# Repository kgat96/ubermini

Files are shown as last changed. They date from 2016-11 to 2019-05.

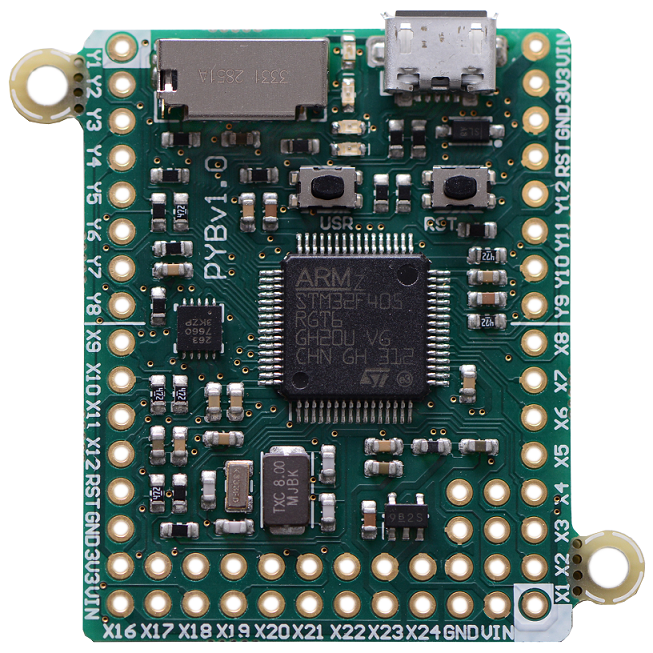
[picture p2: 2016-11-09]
hardware/pyboard/pinout/pybv10b/pybv10b-front-trans.png

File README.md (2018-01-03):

# ubermini

Project Ubermini is an open source wireless development platform suitable for Bluetooth experimentation. Ubermini ships with a capable BLE (Bluetooth Smart) sniffer and can sniff some data from Basic Rate (BR) Bluetooth Classic connections.

clone [Ubertooth](https://github.com/greatscottgadgets/ubertooth) project

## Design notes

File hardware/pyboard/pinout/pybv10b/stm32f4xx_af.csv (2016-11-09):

Port |  | AF0 | AF1 | AF2 | AF3 | AF4 | AF5 | AF6 | AF7 | AF8 | AF9 | AF10 | AF11 | AF12 | AF13 | AF14 | AF15
 |  | SYS | TIM1/2 | TIM3/4/5 | TIM8/9/10/11 | I2C1/2/3 | SPI1/SPI2/I2S2/I2S2ext | SPI3/I2Sext/I2S3 | USART1/2/3/I2S3ext | UART4/5/USART6 | CAN1/CAN2/TIM12/13/14 | OTG_FS/OTG_HS | ETH | FSMC/SDIO/OTG_FS | DCMI |  |  | ADC
PortA | PA0 |  | TIM2_CH1/TIM2_ETR | TIM5_CH1 | TIM8_ETR |  |  |  | USART2_CTS | UART4_TX |  |  | ETH_MII_CRS |  |  |  | EVENTOUT | ADC123_IN0
PortA | PA1 |  | TIM2_CH2 | TIM5_CH2 |  |  |  |  | USART2_RTS | UART4_RX |  |  | ETH_MII_RX_CLK/ETH_RMII__REF_CLK |  |  |  | EVENTOUT | ADC123_IN1
PortA | PA2 |  | TIM2_CH3 | TIM5_CH3 | TIM9_CH1 |  |  |  | USART2_TX |  |  |  | ETH_MDIO |  |  |  | EVENTOUT | ADC123_IN2
PortA | PA3 |  | TIM2_CH4 | TIM5_CH4 | TIM9_CH2 |  |  |  | USART2_RX |  |  | OTG_HS_ULPI_D0 | ETH_MII_COL |  |  |  | EVENTOUT | ADC123_IN3
PortA | PA4 |  |  |  |  |  | SPI1_NSS | SPI3_NSS/I2S3_WS | USART2_CK |  |  |  |  | OTG_HS_SOF | DCMI_HSYNC |  | EVENTOUT | ADC12_IN4
PortA | PA5 |  | TIM2_CH1/TIM2_ETR |  | TIM8_CH1N |  | SPI1_SCK |  |  |  |  | OTG_HS_ULPI_CK |  |  |  |  | EVENTOUT | ADC12_IN5
PortA | PA6 |  | TIM1_BKIN | TIM3_CH1 | TIM8_BKIN |  | SPI1_MISO |  |  |  | TIM13_CH1 |  |  |  | DCMI_PIXCK |  | EVENTOUT | ADC12_IN6
PortA | PA7 |  | TIM1_CH1N | TIM3_CH2 | TIM8_CH1N |  | SPI1_MOSI |  |  |  | TIM14_CH1 |  | ETH_MII_RX_DV/ETH_RMII_CRS_DV |  |  |  | EVENTOUT | ADC12_IN7
PortA | PA8 | MCO1 | TIM1_CH1 |  |  | I2C3_SCL |  |  | USART1_CK |  |  | OTG_FS_SOF |  |  |  |  | EVENTOUT
PortA | PA9 |  | TIM1_CH2 |  |  | I2C3_SMBA |  |  | USART1_TX |  |  |  |  |  | DCMI_D0 |  | EVENTOUT
PortA | PA10 |  | TIM1_CH3 |  |  |  |  |  | USART1_RX |  |  | OTG_FS_ID |  |  | DCMI_D1 |  | EVENTOUT
PortA | PA11 |  | TIM1_CH4 |  |  |  |  |  | USART1_CTS |  | CAN1_RX | OTG_FS_DM |  |  |  |  | EVENTOUT
PortA | PA12 |  | TIM1_ETR |  |  |  |  |  | USART1_RTS |  | CAN1_TX | OTG_FS_DP |  |  |  |  | EVENTOUT
PortA | PA13 | JTMS-SWDIO |  |  |  |  |  |  |  |  |  |  |  |  |  |  | EVENTOUT
PortA | PA14 | JTCK-SWCLK |  |  |  |  |  |  |  |  |  |  |  |  |  |  | EVENTOUT
PortA | PA15 | JTDI | TIM2_CH1/TIM2_ETR |  |  |  | SPI1_NSS | SPI3_NSS/I2S3_WS |  |  |  |  |  |  |  |  | EVENTOUT
PortB | PB0 |  | TIM1_CH2N | TIM3_CH3 | TIM8_CH2N |  |  |  |  |  |  | OTG_HS_ULPI_D1 | ETH_MII_RXD2 |  |  |  | EVENTOUT | ADC12_IN8
PortB | PB1 |  | TIM1_CH3N | TIM3_CH4 | TIM8_CH3N |  |  |  |  |  |  | OTG_HS_ULPI_D2 | ETH_MII_RXD3 |  |  |  | EVENTOUT | ADC12_IN9
PortB | PB2 |  |  |  |  |  |  |  |  |  |  |  |  |  |  |  | EVENTOUT
PortB | PB3 | JTDO/TRACESWO | TIM2_CH2 |  |  |  | SPI1_SCK | SPI3_SCK/I2S3_CK |  |  |  |  |  |  |  |  | EVENTOUT
PortB | PB4 | NJTRST |  | TIM3_CH1 |  |  | SPI1_MISO | SPI3_MISO | I2S3ext_SD |  |  |  |  |  |  |  | EVENTOUT
PortB | PB5 |  |  | TIM3_CH2 |  | I2C1_SMBA | SPI1_MOSI | SPI3_MOSI/I2S3_SD |  |  | CAN2_RX | OTG_HS_ULPI_D7 | ETH_PPS_OUT |  | DCMI_D10 |  | EVENTOUT
PortB | PB6 |  |  | TIM4_CH1 |  | I2C1_SCL |  |  | USART1_TX |  | CAN2_TX |  |  |  | DCMI_D5 |  | EVENTOUT
PortB | PB7 |  |  | TIM4_CH2 |  | I2C1_SDA |  |  | USART1_RX |  |  |  |  | FSMC_NL | DCMI_VSYNC |  | EVENTOUT
PortB | PB8 |  |  | TIM4_CH3 | TIM10_CH1 | I2C1_SCL |  |  |  |  | CAN1_RX |  | ETH_MII_TXD3 | SDIO_D4 | DCMI_D6 |  | EVENTOUT
PortB | PB9 |  |  | TIM4_CH4 | TIM11_CH1 | I2C1_SDA | SPI2_NSS/I2S2_WS |  |  |  | CAN1_TX |  |  | SDIO_D5 | DCMI_D7 |  | EVENTOUT
PortB | PB10 |  | TIM2_CH3 |  |  | I2C2_SCL | SPI2_SCK/I2S2_CK |  | USART3_TX |  |  | OTG_HS_ULPI_D3 | ETH_MII_RX_ER |  |  |  | EVENTOUT
PortB | PB11 |  | TIM2_CH4 |  |  | I2C2_SDA |  |  | USART3_RX |  |  | OTG_HS_ULPI_D4 | ETH_MII_TX_EN/ETH_RMII_TX_EN |  |  |  | EVENTOUT
PortB | PB12 |  | TIM1_BKIN |  |  | I2C2_SMBA | SPI2_NSS/I2S2_WS |  | USART3_CK |  | CAN2_RX | OTG_HS_ULPI_D5 | ETH_MII_TXD0/ETH_RMII_TXD0 | OTG_HS_ID |  |  | EVENTOUT
PortB | PB13 |  | TIM1_CH1N |  |  |  | SPI2_SCK/I2S2_CK |  | USART3_CTS |  | CAN2_TX | OTG_HS_ULPI_D6 | ETH_MII_TXD1/ETH_RMII_TXD1 |  |  |  | EVENTOUT
PortB | PB14 |  | TIM1_CH2N |  | TIM8_CH2N |  | SPI2_MISO | I2S2ext_SD | USART3_RTS |  | TIM12_CH1 |  |  | OTG_HS_DM |  |  | EVENTOUT
PortB | PB15 | RTC_REFIN | TIM1_CH3N |  | TIM8_CH3N |  | SPI2_MOSI/I2S2_SD |  |  |  | TIM12_CH2 |  |  | OTG_HS_DP |  |  | EVENTOUT
PortC | PC0 |  |  |  |  |  |  |  |  |  |  | OTG_HS_ULPI_STP |  |  |  |  | EVENTOUT | ADC123_IN10
PortC | PC1 |  |  |  |  |  |  |  |  |  |  |  | ETH_MDC |  |  |  | EVENTOUT | ADC123_IN11
PortC | PC2 |  |  |  |  |  | SPI2_MISO | I2S2ext_SD |  |  |  | OTG_HS_ULPI_DIR | ETH_MII_TXD2 |  |  |  | EVENTOUT | ADC123_IN12
PortC | PC3 |  |  |  |  |  | SPI2_MOSI/I2S2_SD |  |  |  |  | OTG_HS_ULPI_NXT | ETH_MII_TX_CLK |  |  |  | EVENTOUT | ADC123_IN13
PortC | PC4 |  |  |  |  |  |  |  |  |  |  |  | ETH_MII_RXD0/ETH_RMII_RXD0 |  |  |  | EVENTOUT | ADC123_IN14
PortC | PC5 |  |  |  |  |  |  |  |  |  |  |  | ETH_MII_RXD1/ETH_RMII_RXD1 |  |  |  | EVENTOUT | ADC123_IN15
PortC | PC6 |  |  | TIM3_CH1 | TIM8_CH1 |  | I2S2_MCK |  |  | USART6_TX |  |  |  | SDIO_D6 | DCMI_D0 |  | EVENTOUT
PortC | PC7 |  |  | TIM3_CH2 | TIM8_CH2 |  |  | I2S3_MCK |  | USART6_RX |  |  |  | SDIO_D7 | DCMI_D1 |  | EVENTOUT
PortC | PC8 |  |  | TIM3_CH3 | TIM8_CH3 |  |  |  |  | USART6_CK |  |  |  | SDIO_D0 | DCMI_D2 |  | EVENTOUT
PortC | PC9 | MCO2 |  | TIM3_CH4 | TIM8_CH4 | I2C3_SDA | I2S_CKIN |  |  |  |  |  |  | SDIO_D1 | DCMI_D3 |  | EVENTOUT
PortC | PC10 |  |  |  |  |  |  | SPI3_SCK/I2S3_CK | USART3_TX | UART4_TX |  |  |  | SDIO_D2 | DCMI_D8 |  | EVENTOUT
PortC | PC11 |  |  |  |  |  | I2S3ext_SD | SPI3_MISO | USART3_RX | UART4_RX |  |  |  | SDIO_D3 | DCMI_D4 |  | EVENTOUT
PortC | PC12 |  |  |  |  |  |  | SPI3_MOSI/I2S3_SD | USART3_CK | UART5_TX |  |  |  | SDIO_CK | DCMI_D9 |  | EVENTOUT
PortC | PC13 |  |  |  |  |  |  |  |  |  |  |  |  |  |  |  | EVENTOUT
PortC | PC14 |  |  |  |  |  |  |  |  |  |  |  |  |  |  |  | EVENTOUT
PortC | PC15 |  |  |  |  |  |  |  |  |  |  |  |  |  |  |  | EVENTOUT
PortD | PD0 |  |  |  |  |  |  |  |  |  | CAN1_RX |  |  | FSMC_D2 |  |  | EVENTOUT
PortD | PD1 |  |  |  |  |  |  |  |  |  | CAN1_TX |  |  | FSMC_D3 |  |  | EVENTOUT
PortD | PD2 |  |  | TIM3_ETR |  |  |  |  |  | UART5_RX |  |  |  | SDIO_CMD | DCMI_D11 |  | EVENTOUT
PortD | PD3 |  |  |  |  |  |  |  | USART2_CTS |  |  |  |  | FSMC_CLK |  |  | EVENTOUT
PortD | PD4 |  |  |  |  |  |  |  | USART2_RTS |  |  |  |  | FSMC_NOE |  |  | EVENTOUT
PortD | PD5 |  |  |  |  |  |  |  | USART2_TX |  |  |  |  | FSMC_NWE |  |  | EVENTOUT
PortD | PD6 |  |  |  |  |  |  |  | USART2_RX |  |  |  |  | FSMC_NWAIT |  |  | EVENTOUT
PortD | PD7 |  |  |  |  |  |  |  | USART2_CK |  |  |  |  | FSMC_NE1/FSMC_NCE2 |  |  | EVENTOUT
PortD | PD8 |  |  |  |  |  |  |  | USART3_TX |  |  |  |  | FSMC_D13 |  |  | EVENTOUT
PortD | PD9 |  |  |  |  |  |  |  | USART3_RX |  |  |  |  | FSMC_D14 |  |  | EVENTOUT
PortD | PD10 |  |  |  |  |  |  |  | USART3_CK |  |  |  |  | FSMC_D15 |  |  | EVENTOUT
PortD | PD11 |  |  |  |  |  |  |  | USART3_CTS |  |  |  |  | FSMC_A16 |  |  | EVENTOUT
PortD | PD12 |  |  | TIM4_CH1 |  |  |  |  | USART3_RTS |  |  |  |  | FSMC_A17 |  |  | EVENTOUT
PortD | PD13 |  |  | TIM4_CH2 |  |  |  |  |  |  |  |  |  | FSMC_A18 |  |  | EVENTOUT
PortD | PD14 |  |  | TIM4_CH3 |  |  |  |  |  |  |  |  |  | FSMC_D0 |  |  | EVENTOUT
PortD | PD15 |  |  | TIM4_CH4 |  |  |  |  |  |  |  |  |  | FSMC_D1 |  |  | EVENTOUT
PortE | PE0 |  |  | TIM4_ETR |  |  |  |  |  |  |  |  |  | FSMC_NBL0 | DCMI_D2 |  | EVENTOUT
PortE | PE1 |  |  |  |  |  |  |  |  |  |  |  |  | FSMC_NBL1 | DCMI_D3 |  | EVENTOUT
PortE | PE2 | TRACECLK |  |  |  |  |  |  |  |  |  |  | ETH_MII_TXD3 | FSMC_A23 |  |  | EVENTOUT
PortE | PE3 | TRACED0 |  |  |  |  |  |  |  |  |  |  |  | FSMC_A19 |  |  | EVENTOUT
PortE | PE4 | TRACED1 |  |  |  |  |  |  |  |  |  |  |  | FSMC_A20 | DCMI_D4 |  | EVENTOUT
PortE | PE5 | TRACED2 |  |  | TIM9_CH1 |  |  |  |  |  |  |  |  | FSMC_A21 | DCMI_D6 |  | EVENTOUT
PortE | PE6 | TRACED3 |  |  | TIM9_CH2 |  |  |  |  |  |  |  |  | FSMC_A22 | DCMI_D7 |  | EVENTOUT
PortE | PE7 |  | TIM1_ETR |  |  |  |  |  |  |  |  |  |  | FSMC_D4 |  |  | EVENTOUT
PortE | PE8 |  | TIM1_CH1N |  |  |  |  |  |  |  |  |  |  | FSMC_D5 |  |  | EVENTOUT
PortE | PE9 |  | TIM1_CH1 |  |  |  |  |  |  |  |  |  |  | FSMC_D6 |  |  | EVENTOUT
PortE | PE10 |  | TIM1_CH2N |  |  |  |  |  |  |  |  |  |  | FSMC_D7 |  |  | EVENTOUT
PortE | PE11 |  | TIM1_CH2 |  |  |  |  |  |  |  |  |  |  | FSMC_D8 |  |  | EVENTOUT
PortE | PE12 |  | TIM1_CH3N |  |  |  |  |  |  |  |  |  |  | FSMC_D9 |  |  | EVENTOUT
PortE | PE13 |  | TIM1_CH3 |  |  |  |  |  |  |  |  |  |  | FSMC_D10 |  |  | EVENTOUT
PortE | PE14 |  | TIM1_CH4 |  |  |  |  |  |  |  |  |  |  | FSMC_D11 |  |  | EVENTOUT
PortE | PE15 |  | TIM1_BKIN |  |  |  |  |  |  |  |  |  |  | FSMC_D12 |  |  | EVENTOUT
PortF | PF0 |  |  |  |  | I2C2_SDA |  |  |  |  |  |  |  | FSMC_A0 |  |  | EVENTOUT
PortF | PF1 |  |  |  |  | I2C2_SCL |  |  |  |  |  |  |  | FSMC_A1 |  |  | EVENTOUT
PortF | PF2 |  |  |  |  | I2C2_SMBA |  |  |  |  |  |  |  | FSMC_A2 |  |  | EVENTOUT
PortF | PF3 |  |  |  |  |  |  |  |  |  |  |  |  | FSMC_A3 |  |  | EVENTOUT | ADC3_IN9
PortF | PF4 |  |  |  |  |  |  |  |  |  |  |  |  | FSMC_A4 |  |  | EVENTOUT | ADC3_IN14
PortF | PF5 |  |  |  |  |  |  |  |  |  |  |  |  | FSMC_A5 |  |  | EVENTOUT | ADC3_IN15
PortF | PF6 |  |  |  | TIM10_CH1 |  |  |  |  |  |  |  |  | FSMC_NIORD |  |  | EVENTOUT | ADC3_IN4
PortF | PF7 |  |  |  | TIM11_CH1 |  |  |  |  |  |  |  |  | FSMC_NREG |  |  | EVENTOUT | ADC3_IN5
PortF | PF8 |  |  |  |  |  |  |  |  |  | TIM13_CH1 |  |  | FSMC_NIOWR |  |  | EVENTOUT | ADC3_IN6
PortF | PF9 |  |  |  |  |  |  |  |  |  | TIM14_CH1 |  |  | FSMC_CD |  |  | EVENTOUT | ADC3_IN7
PortF | PF10 |  |  |  |  |  |  |  |  |  |  |  |  | FSMC_INTR |  |  | EVENTOUT | ADC3_IN8
PortF | PF11 |  |  |  |  |  |  |  |  |  |  |  |  |  | DCMI_D12 |  | EVENTOUT
PortF | PF12 |  |  |  |  |  |  |  |  |  |  |  |  | FSMC_A6 |  |  | EVENTOUT
PortF | PF13 |  |  |  |  |  |  |  |  |  |  |  |  | FSMC_A7 |  |  | EVENTOUT
PortF | PF14 |  |  |  |  |  |  |  |  |  |  |  |  | FSMC_A8 |  |  | EVENTOUT
PortF | PF15 |  |  |  |  |  |  |  |  |  |  |  |  | FSMC_A9 |  |  | EVENTOUT
PortG | PG0 |  |  |  |  |  |  |  |  |  |  |  |  | FSMC_A10 |  |  | EVENTOUT
PortG | PG1 |  |  |  |  |  |  |  |  |  |  |  |  | FSMC_A11 |  |  | EVENTOUT
PortG | PG2 |  |  |  |  |  |  |  |  |  |  |  |  | FSMC_A12 |  |  | EVENTOUT
PortG | PG3 |  |  |  |  |  |  |  |  |  |  |  |  | FSMC_A13 |  |  | EVENTOUT
PortG | PG4 |  |  |  |  |  |  |  |  |  |  |  |  | FSMC_A14 |  |  | EVENTOUT
PortG | PG5 |  |  |  |  |  |  |  |  |  |  |  |  | FSMC_A15 |  |  | EVENTOUT
PortG | PG6 |  |  |  |  |  |  |  |  |  |  |  |  | FSMC_INT2 |  |  | EVENTOUT
PortG | PG7 |  |  |  |  |  |  |  |  | USART6_CK |  |  |  | FSMC_INT3 |  |  | EVENTOUT
PortG | PG8 |  |  |  |  |  |  |  |  | USART6_RTS |  |  | ETH_PPS_OUT |  |  |  | EVENTOUT
PortG | PG9 |  |  |  |  |  |  |  |  | USART6_RX |  |  |  | FSMC_NE2/FSMC_NCE3 |  |  | EVENTOUT
PortG | PG10 |  |  |  |  |  |  |  |  |  |  |  |  | FSMC_NCE4_1/FSMC_NE3 |  |  | EVENTOUT
PortG | PG11 |  |  |  |  |  |  |  |  |  |  |  | ETH_MII_TX_EN/ETH_RMII_TX_EN | FSMC_NCE4_2 |  |  | EVENTOUT
PortG | PG12 |  |  |  |  |  |  |  |  | USART6_RTS |  |  |  | FSMC_NE4 |  |  | EVENTOUT
PortG | PG13 |  |  |  |  |  |  |  |  | USART6_CTS |  |  | ETH_MII_TXD0/ETH_RMII_TXD0 | FSMC_A24 |  |  | EVENTOUT
PortG | PG14 |  |  |  |  |  |  |  |  | USART6_TX |  |  | ETH_MII_TXD1/ETH_RMII_TXD1 | FSMC_A25 |  |  | EVENTOUT
PortG | PG15 |  |  |  |  |  |  |  |  | USART6_CTS |  |  |  |  | DCMI_D13 |  | EVENTOUT
PortH | PH0 |  |  |  |  |  |  |  |  |  |  |  |  |  |  |  | EVENTOUT
PortH | PH1 |  |  |  |  |  |  |  |  |  |  |  |  |  |  |  | EVENTOUT
PortH | PH2 |  |  |  |  |  |  |  |  |  |  |  | ETH_MII_CRS |  |  |  | EVENTOUT
PortH | PH3 |  |  |  |  |  |  |  |  |  |  |  | ETH_MII_COL |  |  |  | EVENTOUT
PortH | PH4 |  |  |  |  | I2C2_SCL |  |  |  |  |  | OTG_HS_ULPI_NXT |  |  |  |  | EVENTOUT
PortH | PH5 |  |  |  |  | I2C2_SDA |  |  |  |  |  |  |  |  |  |  | EVENTOUT
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

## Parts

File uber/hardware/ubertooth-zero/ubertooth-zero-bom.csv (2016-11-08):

Reference Designator | Manufacturer | Manufacturer Part Number | Description | Supplier | Supplier Part Number | Price Each | Quantity | Extended Price | Notes
C61,81 | Murata | GRM1555C1HR50CZ01D | CAP CER .5PF 50V C0G 0402 | Mouser | 81-GRM36C0R5C50 | 0.03 | 2 | 0.06
C62 | Murata | GRM1555C1H5R6DZ01D | CAP CER 5.6PF 50V C0G 0402 | Mouser | 81-GRM1555C1H5R6DZ1D | 0.03 | 1 | 0.03
C421,431 | Murata | GRM1555C1H270JZ01D | CAP CER 27PF 50V 5% C0G 0402 | Mouser | 81-GRM1555C1H270JZ01 | 0.03 | 2 | 0.06
C1,4,5 | Murata | GRM1555C1H680JZ01D | CAP CER 68PF 50V 5% C0G 0402 | Mouser | 81-GRM1555C1H680JZ1D | 0.03 | 3 | 0.09
C3 | Murata | GRM155R71E103KA01D | CAP CER 10000PF 25V 10% X7R 0402 | Mouser | 81-GRM36X103K25 | 0.03 | 1 | 0.03
C2,6,7,16,71 | Murata | GRM155R61A104KA01D | CAP CER .1UF 10V 10% X5R 0402 | Mouser | 81-GRM155R61A104KA01 | 0.02 | 4 | 0.08
L62 | Murata | LQG15HS5N6S02D | INDUCTOR 5.6NH 300MA 0402 | Mouser | 81-LQG15HS5N6S02D | 0.04 | 1 | 0.04
L61,81 | Murata | LQW15AN7N5J00D | INDUCTOR 7.5NH 570MA 0402 | Mouser | 81-LQW15AN7N5J00D | 0.31 | 2 | 0.62
L71 | Murata | LQW15AN27NJ00D | INDUCTOR 27NH 280MA 0402 | Mouser | 81-LQW15AN27NJ00D | 0.31 | 1 | 0.31
R451 | KOA Speer | RK73H1ETTP4302F | Thick Film Resistor 1/16W 43K 1% 0402 | Mouser | 660-RK73H1ETTP4302F | 0.06 | 1 | 0.06
U1 | Texas Instruments | CC2400-RTB1 | IC RF TXRX 2.4GHZ LP 48-QFN | Mouser | 595-CC2400-RTB1 | 9.14 | 1 | 9.14
J3 | Connector City | CONREVSMA003.031 | Reverse Polarized SMA Connector | Mouser | 712-CONREVSMA003.031 | 3.08 | 1 | 3.08 | Lower cost alternative: SparkFun WRL-00592 $1.95, SMA also an option
U2 | NXP | LPC1758FBD80,551 | ARM Cortex M3 Micro Controller | Mouser | 771-LPC1758FBD80551 | 8.67 | 1 | 8.67 | may substitute LPC175x
X1 | Abracon | ABMM2-16.000MHZ-E2-T | Crystal +/-20PPM 16MHz | Mouser | 815-ABMM2-16-E2T | 1.16 | 1 | 1.16
X2 | Molex | 48037-1000 | USB & Firewire Connector TYPE A RA SHLDED PLG SMT AU | Mouser | 538-48037-1000 | 2.22 | 1 | 2.22 | better price at Digi-Key
U5 | NXP | IP4220CZ6,125 | ESD Suppressor USB2.0 ESD PROTECT DUAL | Mouser | 771-IP4220CZ6-T/R | 0.18 | 1 | 0.18
U4 | Microchip | MCP1801T-1802I/OT | Low Dropout (LDO) Regulators Hi PSRR 150 mA LDO Vin 10V max Vout 1.8V | Mouser | 579-MCP1801T-1802IOT | 0.52 | 1 | 0.52
U3 | Vishay/Siliconix | SI9183DT-33-T1-E3 | Low Dropout (LDO) Regulator 150mA 3.3V | Mouser | 781-SI9183DT-33-E3 | 0.28 | 1 | 0.28
C14,15,17,18,20,22 | TDK | C1608X7R1E104K | CAP CER 0603 0.1uF 25volts X7R 10% | Mouser | 810-C1608X7R1E104K | 0.03 | 6 | 0.18
R5,6,7,8,9,11 | Xicon | 301-330-RC | Thick Film Resistor 1/16W 330OHMS 5% 0603 | Mouser | 301-330-RC | 0.03 | 6 | 0.18
R1,10,13 | Xicon | 301-10K-RC | Thick Film Resistor 1/16W 10KOHMS 5% 0603 | Mouser | 301-10K-RC | 0.03 | 2 | 0.06
C9 | TDK | C1608C0G1H101J | CAP CER 0603 100pF 50volts C0G 5% | Mouser | 810-C1608C0G1H101J | 0.03 | 1 | 0.03
C8 | TDK | C1608C0G1H221J | CAP CER 0603 220pF 50volts C0G 5% | Mouser | 810-C1608C0G1H221J | 0.03 | 1 | 0.03
R4 | Xicon | 301-1.5K-RC | Thick Film Resistor 1/16W 1.5KOHMS 5% | Mouser | 301-1.5K-RC | 0.03 | 1 | 0.03
R2,3 | Vishay/Dale | CRCW060333R0FKEA | Thick Film Resistor 1/10W 33ohms 1% 0603 | Mouser | 71-CRCW0603-33-E3 | 0.06 | 2 | 0.12
C19,21,23,24 | Murata | GRM188R60J105KA01J | CAP CER 0603 1uF 6.3volts X5R 10% | Mouser | 81-GRM18R60J105KA01J | 0.04 | 4 | 0.16
LEDs |  |  | 0603 LED, various colors |  |  | 0.10 | 6 | 0.60

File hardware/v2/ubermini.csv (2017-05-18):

Id | 代号 | 封装 | 数量 | 名称 | 供应商和REF
1 |  | Symbol_OSHW-Logo_SilkScreen_BIG | 1 | Symbol_OSHW-Logo_SilkScreen_BIG
2 | P3,P2,P7 | U.FL | 3 | sma
3 | U1 | cc2591 | 1 | CC2591
4 | U2 | LQFP-64_10x10mm_Pitch0.5mm | 1 | STM32F405RGTx
5 | C1,C15,C21 | C_0603_HandSoldering | 3 | 100nF
6 | R7,R6 | R_0603_HandSoldering | 2 | 22
7 | D1 | R_0805_HandSoldering | 1 | D
8 | R5,R3,R8,R11,R12,R13,R14,R15 | R_0603_HandSoldering | 8 | 10k
9 | BT1 | Pin_Header_Straight_1x02 | 1 | Battery_Cell
10 | C2 | C_0603_HandSoldering | 1 | 2.2Uf
11 | C3 | C_0603_HandSoldering | 1 | 10uf
12 | C4 | C_0402 | 1 | 2p2
13 | C5 | C_0603_HandSoldering | 1 | 2.2uf
14 | C6,C10,C12,C13 | C_0603_HandSoldering | 4 | 1nF
15 | C7 | C_0603_HandSoldering | 1 | 18nF
16 | C8 | C_0402 | 1 | 1pF
17 | C9 | C_0402 | 1 | 6p8
18 | C11 | C_0603_HandSoldering | 1 | 10pF
19 | C14 | C_0603_HandSoldering | 1 | 68p
20 | C16,C32 | C_0603_HandSoldering | 2 | 10nF
21 | C17,C20 | C_0603_HandSoldering | 2 | 68pF
22 | C18,C19 | C_0603_HandSoldering | 2 | 27pF
23 | C22,C25,C27,C28,C29,C30 | C_0603_HandSoldering | 6 | 4.7uF
24 | C23 | C_0603_HandSoldering | 1 | 1uF
25 | C24,C26,C31 | C_0603_HandSoldering | 3 | 2.2uF
26 | C33 | C_0603_HandSoldering | 1 | 15pF
27 | D2,D3,D4,D5,D6 | LED_0805 | 5 | LED
28 | L1 | C_0402 | 1 | 3nH
29 | L2 | C_0402 | 1 | 2n2
30 | L4 | C_0603_HandSoldering | 1 | FB
31 | P1 | sma | 1 | SMA
32 | P4 | Pin_Header_Straight_1x03 | 1 | uart1
33 | P5 | Pin_Header_Straight_1x03 | 1 | SWD
34 | P6 | Pin_Header_Straight_2x03 | 1 | boot
35 | R1 | R_0603_HandSoldering | 1 | 100k
36 | R2 | R_0603_HandSoldering | 1 | 4k3
37 | R4 | R_0603_HandSoldering | 1 | 43k
38 | R9 | R_0603_HandSoldering | 1 | 49.9k
39 | R10 | R_0603_HandSoldering | 1 | 30.1k
40 | SW1 | SW_SPST_FSMSM | 1 | SW_PUSH
41 | U4 | tps712 | 1 | TPS712XX
42 | U5 | winband_spi_flash | 1 | M25PX32-VMW
43 | J1 | USB_Mini-B_s | 1 | USB_OTG
44 | U3 | cc2400 | 1 | CC2400
45 | Y1 | 3225 | 1 | 16m
46 |  | kg_logo | 1 | LOGO

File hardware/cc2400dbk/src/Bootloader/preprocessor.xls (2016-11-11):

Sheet: defines.h
Replace all code segment definitions in the linker file with the following line:
-Z(CODE)INTVEC,FAR_F,SWITCH,CODE=1F800-1FFFF
Create a file (defines.h) containing the following:
/* definitions generated by preprocessor, copy into defines.h */
#ifndef | PPINC
#define | _ATMEGA128 | // device select: _ATMEGAxxxx
#define | _B1024 | // boot size select: _Bxxx (words)
#include | "iom128.h"
/* definitions for UART control */
#define | BAUD_RATE_LOW_REG | UBRR0L
#define | UART_CONTROL_REG | UCSR0B
#define | ENABLE_TRANSMITTER_BIT | TXEN0
#define | ENABLE_RECEIVER_BIT | RXEN0
#define | UART_STATUS_REG | UCSR0A
#define | TRANSMIT_COMPLETE_BIT | TXC0
#define | RECEIVE_COMPLETE_BIT | RXC0
#define | UART_DATA_REG | UDR0
/* definitions for SPM control */
#define | LOAD_SPM_CONTROL_REGISTER_MACRO | STS SPMCSR, R18
#define | GET_SPM_CONTROL_REGISTER_MACRO | LDS R18, SPMCSR
#define | REENABLE_RWW_BIT | RWWSRE
#define | LARGE_MEMORY
#define | PAGESIZE | 256
#define | APP_END | 129024
/* definitions for AVRProg communication */
#define | PARTCODE | 0x44
#define | SIGNATURE_BYTE_1 | 0x1E
#define | SIGNATURE_BYTE_2 | 0x97
#define | SIGNATURE_BYTE_3 | 0x02
/* define pin for enter-self-prog-mode */
#define | PROGPORT | PORTD
#define | PROGPIN | PIND
#define | PROGCTRL | (1<<PD4)
#define | PROGMODE | !(PROGPIN & PROGCTRL)
/* indicate preprocessor result included */
#define | PPINC
#endif

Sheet: Part definitions
Device | Include file name | Page size (words) | NRWW section size (pages) | Total memory (pages) | Part code (AVRProg) | Signature byte 1 | Signature byte 2 | Signature byte 3 | Baud rate register low | UART Control register | UART Status register | Transmitter enable bit | Receiver enable bit | Transmit complete bit | Receive complete bit | UART Data register | SPM Control register | Use extended IO addressing on SPM Control register | Re-enable RWW section bit | Comments
ATmega8 | iom8.h | 32 | 32 | 128 | 0x77 | 0x1E | 0x93 | 0x07 | UBRRL | UCSRB | UCSRA | TXEN | RXEN | TXC | RXC | UDR | SPMCR | FALSE | RWWSRE
ATmega8515 | iom8515.h | 32 | 32 | 128 |  | 0x1E | 0x93 | 0x06 | UBRRL | UCSRB | UCSRA | TXEN | RXEN | TXC | RXC | UDR | SPMCR | FALSE | RWWSRE
ATmega8535 | iom8535.h | 32 | 32 | 128 |  | 0x1E | 0x93 | 0x08 | UBRRL | UCSRB | UCSRA | TXEN | RXEN | TXC | RXC | UDR | SPMCR | FALSE | RWWSRE
ATmega16 | iom16.h | 64 | 16 | 128 | 0x75 | 0x1E | 0x94 | 0x03 | UBRRL | UCSRB | UCSRA | TXEN | RXEN | TXC | RXC | UDR | SPMCR | FALSE | RWWSRE
ATmega162 | iom162.h | 64 | 16 | 128 |  | 0x1E | 0x94 | 0x04 | UBRR0L | UCSR0B | UCSR0A | TXEN0 | RXEN0 | TXC0 | RXC0 | UDR0 | SPMCR | FALSE | RWWSRE
ATmega163 | iom163.h | 64 | 16 | 128 | 0x66 | 0x1E | 0x94 | 0x02 | UBRRLO | UCSRB | UCSRA | TXEN | RXEN | TXC | RXC | UDR | SPMCR | FALSE | ASRE | All memory is NRWW
ATmega169 | iom169.h | 64 | 16 | 128 |  | 0x1E | 0x94 | 0x05 | UBRR0L | UCSR0B | UCSR0A | TXEN0 | RXEN0 | TXC0 | RXC0 | UDR0 | SPMCSR | FALSE | RWWSRE
ATmega32 | iom32.h | 64 | 32 | 256 |  | 0x1E | 0x95 | 0x02 | UBRRL | UCSRB | UCSRA | TXEN | RXEN | TXC | RXC | UDR | SPMCR | FALSE | RWWSRE
ATmega323 | iom323.h | 64 | 16 | 256 | 0x73 | 0x1E | 0x95 | 0x01 | UBRRL | UCSRB | UCSRA | TXEN | RXEN | TXC | RXC | UDR | SPMCR | FALSE | ASRE | All memory is NRWW
ATmega64 | iom64.h | 128 | 32 | 256 |  | 0x1E | 0x96 | 0x02 | UBRRL | UCSRB | UCSRA | TXEN | RXEN | TXC | RXC | UDR | SPMCR | TRUE | RWWSRE
ATmega128 | iom128.h | 128 | 32 | 512 | 0x44 | 0x1E | 0x97 | 0x02 | UBRR0L | UCSR0B | UCSR0A | TXEN0 | RXEN0 | TXC0 | RXC0 | UDR0 | SPMCSR | TRUE | RWWSRE

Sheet: Processing
Part selected | ATMEGA128 | Selected part
Boot size selected (words) | 1024 | Boot loader section size
Boot size selected (bytes) | 2048
Boot size selected (pages) | 8
IO definition file | "iom128.h" | Name of IO definition file
Part code | 0x44 | Used by AVRprog
Signature byte 1 | 0x1E | Device specific signature bytes
Signature byte 2 | 0x97
Signature byte 3 | 0x02
Page size (words) | 128
Page size (bytes) | 256
NRWW section size (pages) | 32
NRWW section size (bytes) | 8192
Boot too large ? | FALSE | Selected boot loader size too large ?
Boot too small ? | FALSE | Selected boot loader size too small ?
Boot OK ? | TRUE | Selected boot loader size inside allowed range ?
Total Flash size (pages) | 512
Total Flash size (bytes) | 131072
Application size (pages) | 504
Application size (bytes) | 129024
Baud rate low register | UBRR0L | Register names for UART
UART Control register | UCSR0B
UART Status register | UCSR0A
Transmitter enable bit | TXEN0
Receiver enable bit | RXEN0
Transmit complete bit | TXC0
Receive complete bit | RXC0
UART Data register | UDR0
SPM Control register | SPMCSR | Definition for using the SPM instruction
Use extended IO addressing | TRUE
Register used | R18
Load SPM control register | STS SPMCSR, R18
Get SPM control register | LDS R18, SPMCSR
Re-enable RWW section bit | RWWSRE

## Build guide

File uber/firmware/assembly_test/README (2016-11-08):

Follow this procedure to test, rework, and program a new Ubertooth One.  For
reference, see ubertooth-one-hardware/ubertooth-one-assembly.pdf and
ubertooth-one-hardware/ubertooth-one-schematic.pdf in the release package or
use KiCad to view the design files located in hardware/ubertooth-one.

Required Equipment

  - Equipment Under Test (EUT): Ubertooth One with 2 dBi antenna

  - Personal Computer (PC) with two open USB ports

  - Pogoprog, a serial programmer for Ubertooth One

  - USB Mini-B cable to connect Pogoprog to PC

  - USB A extension cable or USB hub to allow access to underside of Ubertooth
	One while it is plugged into the PC

  - A Bluetooth device such as a mobile phone

  - Multi-meter (voltmeter and continuity tester)

Required Software

  - lpc21isp

Visual Inspection

  1. Check EUT for missing components.

  2. Check that components are installed with the correct orientation and
  placement.

  3. Check in particular that R1 and C12 are not soldered together (one side,
  GND, may be together, but the side closest to U1 should not be).

Electrical Inspection

  1. Verify no conductivity across C18.

  2. Verify no conductivity across C22.

  3. Verify no conductivity across C32.
 
  If shorts are detected, carefully inspect (in order) the three capacitors
  listed above, the voltage regulator (U7), bypass capacitors, and all IC pins.

Power On EUT

  1. Connect to EUT the 2 dBi antenna.  Check that the antenna fully screws
  onto the RP-SMA connector.

  2. Plug EUT in to PC with USB A extension cable or USB hub.

  3. The "RST" LED (D5) should be illuminated.  No other LED should be fully
  illuminated, though they may be dimly lit.  D5 indicates that U4 has been
  powered on and passed reset.  If D5 does not illuminate, check D5, R8, R9,
  and pins 11 and 14 on U4.

Program EUT with assembly_test Firmware

  1. Ensure EUT is plugged into PC.

  2. Plug Pogoprog into PC with USB Mini-B cable.

  3. Hold Pogoprog against the "PROGRAM" pads on the underside of EUT as shown
  in the photograph:

    http://ubertooth.sourceforge.net/hardware/program/

  4. on the PC, execute:

    $ make program

  If you have not yet compiled the assembly_test firmware, you will need to
  have a gcc/arm environment set up.  See:

    http://ubertooth.sourceforge.net/firmware/develop/

  5. The 'make program' command will indicate "Download Finished . . . Now
  launching the brand new code" if successful.  If it was not successful, check
  the orientation and contact between the Pogoprog and sample Ubertooth One,
  make sure both are plugged in, and try again.

Automated Test

  1. Unplug EUT from PC and plug back in.

  2. "RST" LED (D5) should illuminate immediately and remain on throughout this
  test.

  3. "TX" LED (D2), "RX" LED (D3), and "USR" LED (D4) should flash twice
  together.  Flashing indicates that the test program is executing on U4.  If
  any of the three LEDs do not flash, check that LED, the adjacent resistor,
  and pins 73, 74, and 75 of U4.

  4. Next, "1V8" LED (D1) should illuminate and remain on.  This indicates that
  U3 is powered on.  If D1 does not illuminate, check D1, R3, R4, U7, and pin
  72 of U4.

  5. Next, "TX" LED (D2) should flash twice and then illuminate and remain on.
  This indicates that U4 is able to communicate with U3.  If D2 does not flash
  and illuminate, check pins 25-35 on U3 and pins 53, 54, 58, 59, 60, and 70 on
  U4.  Check that there is a 1.8 Volt potential across C18.  Check that there
  is a 3.3 Volt potential across C25.

  6. Next, "RX" LED (D3) should flash four times quickly and then illuminate
  and remain on.  This indicates that the 16 MHz crystal oscillator is active
  and supplying clock to both U3 and U4.  If D3 does not flash and illuminate,
  check X1, C19, C21, C29, C31, pins 21, 42, and 43 on U3, and pins 19 and 20
  on U4.

  7. At this point, four LEDs (D1, D2, D3, and D5) should all be on.

  8. Use a mobile phone or other Bluetooth device approximately 1 meter away
  from EUT to initiate an inquiry.  This function is typically called “search
  for new Bluetooth devices” or similar.

  9. During the inquiry, "USR" LED (D4) may flash and should then illuminate
  and remain on.  If D4 flashes but does not remain on after the inquiry, this
  indicates that RF performance is poor.  If D4 does not flash at all, this
  indicates a total RF failure.  Check that a 2 dBi antenna is securely
  connected to P1.  Check L1, L2, C1, C3, and C5.  Check all pins on U1 and U3.
  Check R1, R2, and R17.  Check all bypass capacitors around U1 and U3.  Check
  pins 50, 51, 61, 62, 63, 64, 65, 68, and 69 on U4.

  10. After D4 illuminates, the "USB" LED (D6) may flash and should then
  illuminate and remain on.  This indicates that the PC has established USB
  communication with EUT.  With some non-Linux operating systems, D6 may not
  illuminate.  Depending on the OS running on the PC, you might see a "found
  new hardware" or "install device driver software" dialog instead of
  illumination of D6.  You should be able to use operating system logging or
  reporting (e.g. dmesg on Linux) to see that a USB device with the product
  name "ubertooth assembly_test" has been detected.  This indicates success.
  Cancel any dialog and visually inspect D6 and R15.

  11. If all six LEDs are on (with the possible exception of D6 as mentioned
  above), the Automated Test is successful.  To repeat the Automated Test,
  unplug EUT from PC and plug in again.

Test Complete

  If your Ubertooth One has passed the assembly test procedure, the recommended
  next steps are:

  1. Install the USB bootloader on your Ubertooth One.  See:

	firmware/bootloader/README

  2. Use the bootloader to install the bluetooth_rxtx application firmware.
  See:

    host/usb_dfu/README

  3. Follow the Getting Started guide:

    http://ubertooth.sourceforge.net/usage/start/

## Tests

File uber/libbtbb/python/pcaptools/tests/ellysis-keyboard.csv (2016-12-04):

Depth | Time | Name | Data
0 | 7.248613000 | HID Input 1 | 01 00 00 00 00 00 00 00 00
0 | 7.249863000 | HID Input 1 | 01 00 00 28 00 00 00 00 00
0 | 7.251113000 | HID Input 1 | 01 00 00 00 00 00 00 00 00
0 | 10.646359000 | HID Input 1 | 01 00 00 28 00 00 00 00 00
0 | 10.658858750 | HID Input 1 | 01 00 00 00 00 00 00 00 00
0 | 10.681358750 | HID Input 1 | 01 00 00 28 00 00 00 00 00
0 | 10.758865000 | HID Input 1 | 01 00 00 00 00 00 00 00 00
0 | 10.893876750 | HID Input 1 | 01 00 00 28 00 00 00 00 00
0 | 10.983884250 | HID Input 1 | 01 00 00 00 00 00 00 00 00
0 | 12.558997750 | HID Input 1 | 01 02 00 00 00 00 00 00 00
0 | 13.009032500 | HID Input 1 | 01 02 00 08 00 00 00 00 00
0 | 13.144044625 | HID Input 1 | 01 00 00 08 00 00 00 00 00
0 | 13.189048625 | HID Input 1 | 01 00 00 00 00 00 00 00 00
0 | 13.324059500 | HID Input 1 | 01 00 00 11 00 00 00 00 00
0 | 13.414067500 | HID Input 1 | 01 00 00 11 17 00 00 00 00
0 | 13.459070500 | HID Input 1 | 01 00 00 17 00 00 00 00 00
0 | 13.504074375 | HID Input 1 | 01 00 00 00 00 00 00 00 00
0 | 13.549077875 | HID Input 1 | 01 00 00 08 00 00 00 00 00
0 | 13.594078750 | HID Input 1 | 01 00 00 08 15 00 00 00 00
0 | 13.684083375 | HID Input 1 | 01 00 00 15 00 00 00 00 00
0 | 13.729087500 | HID Input 1 | 01 00 00 00 00 00 00 00 00
0 | 13.774091625 | HID Input 1 | 01 00 00 2C 00 00 00 00 00
0 | 13.864099125 | HID Input 1 | 01 00 00 2C 17 00 00 00 00
0 | 13.865349125 | HID Input 1 | 01 00 00 17 00 00 00 00 00
0 | 13.954107375 | HID Input 1 | 01 00 00 00 00 00 00 00 00
0 | 13.955357375 | HID Input 1 | 01 00 00 0B 00 00 00 00 00
0 | 13.999108000 | HID Input 1 | 01 00 00 0B 08 00 00 00 00
0 | 14.044112125 | HID Input 1 | 01 00 00 08 00 00 00 00 00
0 | 14.089117000 | HID Input 1 | 01 00 00 00 00 00 00 00 00
0 | 14.134119250 | HID Input 1 | 01 00 00 2C 00 00 00 00 00
0 | 14.269131375 | HID Input 1 | 01 00 00 00 00 00 00 00 00
0 | 14.270381375 | HID Input 1 | 01 02 00 00 00 00 00 00 00
0 | 14.404141250 | HID Input 1 | 01 02 00 17 00 00 00 00 00
0 | 14.449145125 | HID Input 1 | 01 02 00 00 00 00 00 00 00
0 | 14.584155625 | HID Input 1 | 01 02 00 06 00 00 00 00 00
0 | 14.674164250 | HID Input 1 | 01 02 00 00 00 00 00 00 00
0 | 14.675414250 | HID Input 1 | 01 02 00 13 00 00 00 00 00
0 | 14.809176000 | HID Input 1 | 01 02 00 00 00 00 00 00 00
0 | 14.854179250 | HID Input 1 | 01 00 00 00 00 00 00 00 00
0 | 14.855429250 | HID Input 1 | 01 00 00 2C 00 00 00 00 00
0 | 14.944184000 | HID Input 1 | 01 00 00 2C 16 00 00 00 00
0 | 14.989186250 | HID Input 1 | 01 00 00 16 00 00 00 00 00
0 | 15.034189500 | HID Input 1 | 01 00 00 16 08 00 00 00 00
0 | 15.079194375 | HID Input 1 | 01 00 00 08 00 00 00 00 00
0 | 15.169201125 | HID Input 1 | 01 00 00 00 00 00 00 00 00
0 | 15.214205250 | HID Input 1 | 01 00 00 14 00 00 00 00 00
0 | 15.349217625 | HID Input 1 | 01 00 00 00 00 00 00 00 00
0 | 15.350467625 | HID Input 1 | 01 00 00 18 00 00 00 00 00
0 | 15.394222125 | HID Input 1 | 01 00 00 18 08 00 00 00 00
0 | 15.439224500 | HID Input 1 | 01 00 00 08 00 00 00 00 00
0 | 15.484228000 | HID Input 1 | 01 00 00 00 00 00 00 00 00
0 | 15.619238750 | HID Input 1 | 01 00 00 11 06 00 00 00 00
0 | 15.620488750 | HID Input 1 | 01 00 00 06 00 00 00 00 00
0 | 15.709246125 | HID Input 1 | 01 00 00 06 08 00 00 00 00
0 | 15.710496125 | HID Input 1 | 01 00 00 08 00 00 00 00 00
0 | 15.754250625 | HID Input 1 | 01 00 00 08 2C 00 00 00 00
0 | 15.799253375 | HID Input 1 | 01 00 00 2C 00 00 00 00 00
0 | 15.844256875 | HID Input 1 | 01 00 00 2C 11 00 00 00 00
0 | 15.889262250 | HID Input 1 | 01 00 00 11 00 00 00 00 00
0 | 15.934265375 | HID Input 1 | 01 00 00 11 18 00 00 00 00
0 | 15.979269125 | HID Input 1 | 01 00 00 18 00 00 00 00 00
0 | 16.024272875 | HID Input 1 | 01 00 00 00 00 00 00 00 00
0 | 16.114280375 | HID Input 1 | 01 00 00 10 00 00 00 00 00
0 | 16.249286750 | HID Input 1 | 01 00 00 10 05 00 00 00 00
0 | 16.294289875 | HID Input 1 | 01 00 00 05 00 00 00 00 00
0 | 16.295540000 | HID Input 1 | 01 00 00 00 00 00 00 00 00
0 | 16.384296125 | HID Input 1 | 01 00 00 08 00 00 00 00 00
0 | 16.474304000 | HID Input 1 | 01 00 00 08 15 00 00 00 00
0 | 16.519306375 | HID Input 1 | 01 00 00 15 00 00 00 00 00
0 | 16.564310750 | HID Input 1 | 01 00 00 00 00 00 00 00 00
0 | 16.834333625 | HID Input 1 | 01 20 00 00 00 00 00 00 00
0 | 16.924341375 | HID Input 1 | 01 20 00 33 00 00 00 00 00
0 | 17.014348625 | HID Input 1 | 01 00 00 33 00 00 00 00 00
0 | 17.059353250 | HID Input 1 | 01 00 00 00 00 00 00 00 00
0 | 17.194365625 | HID Input 1 | 01 00 00 2C 00 00 00 00 00
0 | 17.329375625 | HID Input 1 | 01 00 00 00 00 00 00 00 00
0 | 17.330625625 | HID Input 1 | 01 00 00 17 00 00 00 00 00
0 | 17.419381000 | HID Input 1 | 01 00 00 00 00 00 00 00 00
0 | 17.420631000 | HID Input 1 | 01 00 00 0B 00 00 00 00 00
0 | 17.509384500 | HID Input 1 | 01 00 00 0B 08 00 00 00 00
0 | 17.510634375 | HID Input 1 | 01 00 00 08 00 00 00 00 00
0 | 17.554388500 | HID Input 1 | 01 00 00 08 2C 00 00 00 00
0 | 17.599393125 | HID Input 1 | 01 00 00 2C 00 00 00 00 00
0 | 17.689399750 | HID Input 1 | 01 00 00 00 00 00 00 00 00
0 | 17.734403750 | HID Input 1 | 01 00 00 13 00 00 00 00 00
0 | 17.869416125 | HID Input 1 | 01 00 00 00 00 00 00 00 00
0 | 17.870666125 | HID Input 1 | 01 00 00 15 00 00 00 00 00
0 | 17.959421875 | HID Input 1 | 01 00 00 00 00 00 00 00 00
0 | 18.004424875 | HID Input 1 | 01 00 00 12 00 00 00 00 00
0 | 18.184440500 | HID Input 1 | 01 00 00 00 00 00 00 00 00
0 | 18.185690625 | HID Input 1 | 01 00 00 17 00 00 00 00 00
0 | 18.274448625 | HID Input 1 | 01 00 00 00 00 00 00 00 00
0 | 18.319453375 | HID Input 1 | 01 00 00 12 00 00 00 00 00
0 | 18.409461000 | HID Input 1 | 01 00 00 00 00 00 00 00 00
0 | 18.454464375 | HID Input 1 | 01 00 00 06 00 00 00 00 00
0 | 18.544471500 | HID Input 1 | 01 00 00 06 12 00 00 00 00
0 | 18.545721500 | HID Input 1 | 01 00 00 12 00 00 00 00 00
0 | 18.634478875 | HID Input 1 | 01 00 00 00 00 00 00 00 00
0 | 18.724483000 | HID Input 1 | 01 00 00 0F 00 00 00 00 00
0 | 18.814490375 | HID Input 1 | 01 00 00 0F 2C 00 00 00 00
0 | 18.859493750 | HID Input 1 | 01 00 00 2C 00 00 00 00 00
0 | 18.949501375 | HID Input 1 | 01 00 00 00 00 00 00 00 00
0 | 18.994505500 | HID Input 1 | 01 00 00 18 00 00 00 00 00
0 | 19.129516125 | HID Input 1 | 01 00 00 18 16 00 00 00 00
0 | 19.130766250 | HID Input 1 | 01 00 00 16 00 00 00 00 00
0 | 19.219524125 | HID Input 1 | 01 00 00 16 08 00 00 00 00
0 | 19.220773875 | HID Input 1 | 01 00 00 08 00 00 00 00 00
0 | 19.309531000 | HID Input 1 | 01 00 00 00 00 00 00 00 00
0 | 19.354534125 | HID Input 1 | 01 00 00 16 00 00 00 00 00
0 | 19.444542000 | HID Input 1 | 01 00 00 16 2C 00 00 00 00
0 | 19.445792000 | HID Input 1 | 01 00 00 2C 00 00 00 00 00
0 | 19.579553625 | HID Input 1 | 01 00 00 2C 16 00 00 00 00
0 | 19.580803625 | HID Input 1 | 01 00 00 16 00 00 00 00 00
0 | 19.669561125 | HID Input 1 | 01 00 00 16 08 00 00 00 00
0 | 19.714563625 | HID Input 1 | 01 00 00 08 00 00 00 00 00
0 | 19.759568375 | HID Input 1 | 01 00 00 00 00 00 00 00 00
0 | 19.850826125 | HID Input 1 | 01 00 00 14 00 00 00 00 00
0 | 19.939581000 | HID Input 1 | 01 00 00 00 00 00 00 00 00
0 | 19.940831125 | HID Input 1 | 01 00 00 18 00 00 00 00 00
0 | 20.029584250 | HID Input 1 | 01 00 00 18 08 00 00 00 00
0 | 20.074588375 | HID Input 1 | 01 00 00 08 00 00 00 00 00
0 | 20.075838500 | HID Input 1 | 01 00 00 00 00 00 00 00 00
0 | 20.164594500 | HID Input 1 | 01 00 00 11 00 00 00 00 00
0 | 20.209599125 | HID Input 1 | 01 00 00 11 06 00 00 00 00
0 | 20.254602250 | HID Input 1 | 01 00 00 06 00 00 00 00 00
0 | 20.299605750 | HID Input 1 | 01 00 00 08 00 00 00 00 00
0 | 20.344609375 | HID Input 1 | 01 00 00 08 2C 00 00 00 00
0 | 20.390862750 | HID Input 1 | 01 00 00 2C 00 00 00 00 00
0 | 20.479621250 | HID Input 1 | 01 00 00 2C 11 00 00 00 00
0 | 20.480871250 | HID Input 1 | 01 00 00 11 00 00 00 00 00
0 | 20.524623750 | HID Input 1 | 01 00 00 11 18 00 00 00 00
0 | 20.569627750 | HID Input 1 | 01 00 00 18 00 00 00 00 00
0 | 20.614630625 | HID Input 1 | 01 00 00 00 00 00 00 00 00
0 | 20.659633750 | HID Input 1 | 01 00 00 10 00 00 00 00 00
0 | 20.794646250 | HID Input 1 | 01 00 00 10 05 00 00 00 00
0 | 20.839650500 | HID Input 1 | 01 00 00 05 00 00 00 00 00
0 | 20.840900375 | HID Input 1 | 01 00 00 00 00 00 00 00 00
0 | 20.929658125 | HID Input 1 | 01 00 00 08 00 00 00 00 00
0 | 20.974661000 | HID Input 1 | 01 00 00 08 15 00 00 00 00
0 | 21.019666125 | HID Input 1 | 01 00 00 15 00 00 00 00 00
0 | 21.109672625 | HID Input 1 | 01 00 00 00 00 00 00 00 00
0 | 21.110922625 | HID Input 1 | 01 00 00 16 00 00 00 00 00
0 | 21.199678625 | HID Input 1 | 01 00 00 16 2C 00 00 00 00
0 | 21.244683250 | HID Input 1 | 01 00 00 2C 00 00 00 00 00
0 | 21.289683500 | HID Input 1 | 01 00 00 00 00 00 00 00 00
0 | 21.334685625 | HID Input 1 | 01 00 00 17 00 00 00 00 00
0 | 21.379689625 | HID Input 1 | 01 00 00 17 12 00 00 00 00
0 | 21.424694000 | HID Input 1 | 01 00 00 12 00 00 00 00 00
0 | 21.425944125 | HID Input 1 | 01 00 00 12 2C 00 00 00 00
0 | 21.514699625 | HID Input 1 | 01 00 00 2C 00 00 00 00 00
0 | 21.515949625 | HID Input 1 | 01 00 00 2C 04 00 00 00 00
0 | 21.604709125 | HID Input 1 | 01 00 00 04 00 00 00 00 00
0 | 21.605959125 | HID Input 1 | 01 00 00 00 00 00 00 00 00
0 | 21.694713500 | HID Input 1 | 01 00 00 06 00 00 00 00 00
0 | 21.784722750 | HID Input 1 | 01 00 00 06 0E 00 00 00 00
0 | 21.785972625 | HID Input 1 | 01 00 00 0E 00 00 00 00 00
0 | 21.829726625 | HID Input 1 | 01 00 00 00 00 00 00 00 00
0 | 22.009742500 | HID Input 1 | 01 00 00 11 00 00 00 00 00
0 | 22.010992625 | HID Input 1 | 01 00 00 11 12 00 00 00 00
0 | 22.054743875 | HID Input 1 | 01 00 00 12 00 00 00 00 00
0 | 22.144752500 | HID Input 1 | 01 00 00 12 1A 00 00 00 00
0 | 22.146002500 | HID Input 1 | 01 00 00 1A 00 00 00 00 00
0 | 22.189756125 | HID Input 1 | 01 00 00 1A 08 00 00 00 00
0 | 22.191006125 | HID Input 1 | 01 00 00 00 00 00 00 00 00
0 | 22.234757000 | HID Input 1 | 01 00 00 0F 00 00 00 00 00
0 | 22.414772750 | HID Input 1 | 01 00 00 00 00 00 00 00 00
0 | 22.416022875 | HID Input 1 | 01 00 00 07 00 00 00 00 00
0 | 22.549782750 | HID Input 1 | 01 00 00 00 00 00 00 00 00
0 | 23.269841500 | HID Input 1 | 01 00 00 0A 00 00 00 00 00
0 | 23.359849625 | HID Input 1 | 01 00 00 0A 08 00 00 00 00
0 | 23.404853625 | HID Input 1 | 01 00 00 08 00 00 00 00 00
0 | 23.494860375 | HID Input 1 | 01 00 00 00 00 00 00 00 00
0 | 23.629872625 | HID Input 1 | 01 00 00 2C 00 00 00 00 00
0 | 23.764884000 | HID Input 1 | 01 00 00 00 00 00 00 00 00
0 | 23.809888500 | HID Input 1 | 01 00 00 17 00 00 00 00 00
0 | 23.899893375 | HID Input 1 | 01 00 00 17 0B 00 00 00 00
0 | 23.901143375 | HID Input 1 | 01 00 00 0B 00 00 00 00 00
0 | 23.944895500 | HID Input 1 | 01 00 00 0B 08 00 00 00 00
0 | 23.989898500 | HID Input 1 | 01 00 00 08 00 00 00 00 00
0 | 24.034901500 | HID Input 1 | 01 00 00 08 2C 00 00 00 00
0 | 24.036151500 | HID Input 1 | 01 00 00 2C 00 00 00 00 00
0 | 24.079906625 | HID Input 1 | 01 00 00 2C 15 00 00 00 00
0 | 24.169913375 | HID Input 1 | 01 00 00 2C 15 08 00 00 00
0 | 24.171163250 | HID Input 1 | 01 00 00 2C 08 00 00 00 00
0 | 24.214916375 | HID Input 1 | 01 00 00 08 00 00 00 00 00
0 | 24.216166375 | HID Input 1 | 01 00 00 00 00 00 00 00 00
0 | 24.259920750 | HID Input 1 | 01 00 00 06 00 00 00 00 00
0 | 24.394933000 | HID Input 1 | 01 00 00 00 00 00 00 00 00
0 | 24.439935000 | HID Input 1 | 01 00 00 0C 00 00 00 00 00
0 | 24.574946625 | HID Input 1 | 01 00 00 00 00 00 00 00 00
0 | 24.619951625 | HID Input 1 | 01 00 00 13 00 00 00 00 00
0 | 24.754963125 | HID Input 1 | 01 00 00 13 17 00 00 00 00
0 | 24.756213125 | HID Input 1 | 01 00 00 17 00 00 00 00 00
0 | 24.844968875 | HID Input 1 | 01 00 00 00 00 00 00 00 00
0 | 24.979979750 | HID Input 1 | 01 00 00 2C 00 00 00 00 00
0 | 25.024984125 | HID Input 1 | 01 00 00 00 00 00 00 00 00
0 | 25.610031625 | HID Input 1 | 01 00 00 12 00 00 00 00 00
0 | 25.700039125 | HID Input 1 | 01 00 00 12 09 00 00 00 00
0 | 25.745042375 | HID Input 1 | 01 00 00 09 00 00 00 00 00
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

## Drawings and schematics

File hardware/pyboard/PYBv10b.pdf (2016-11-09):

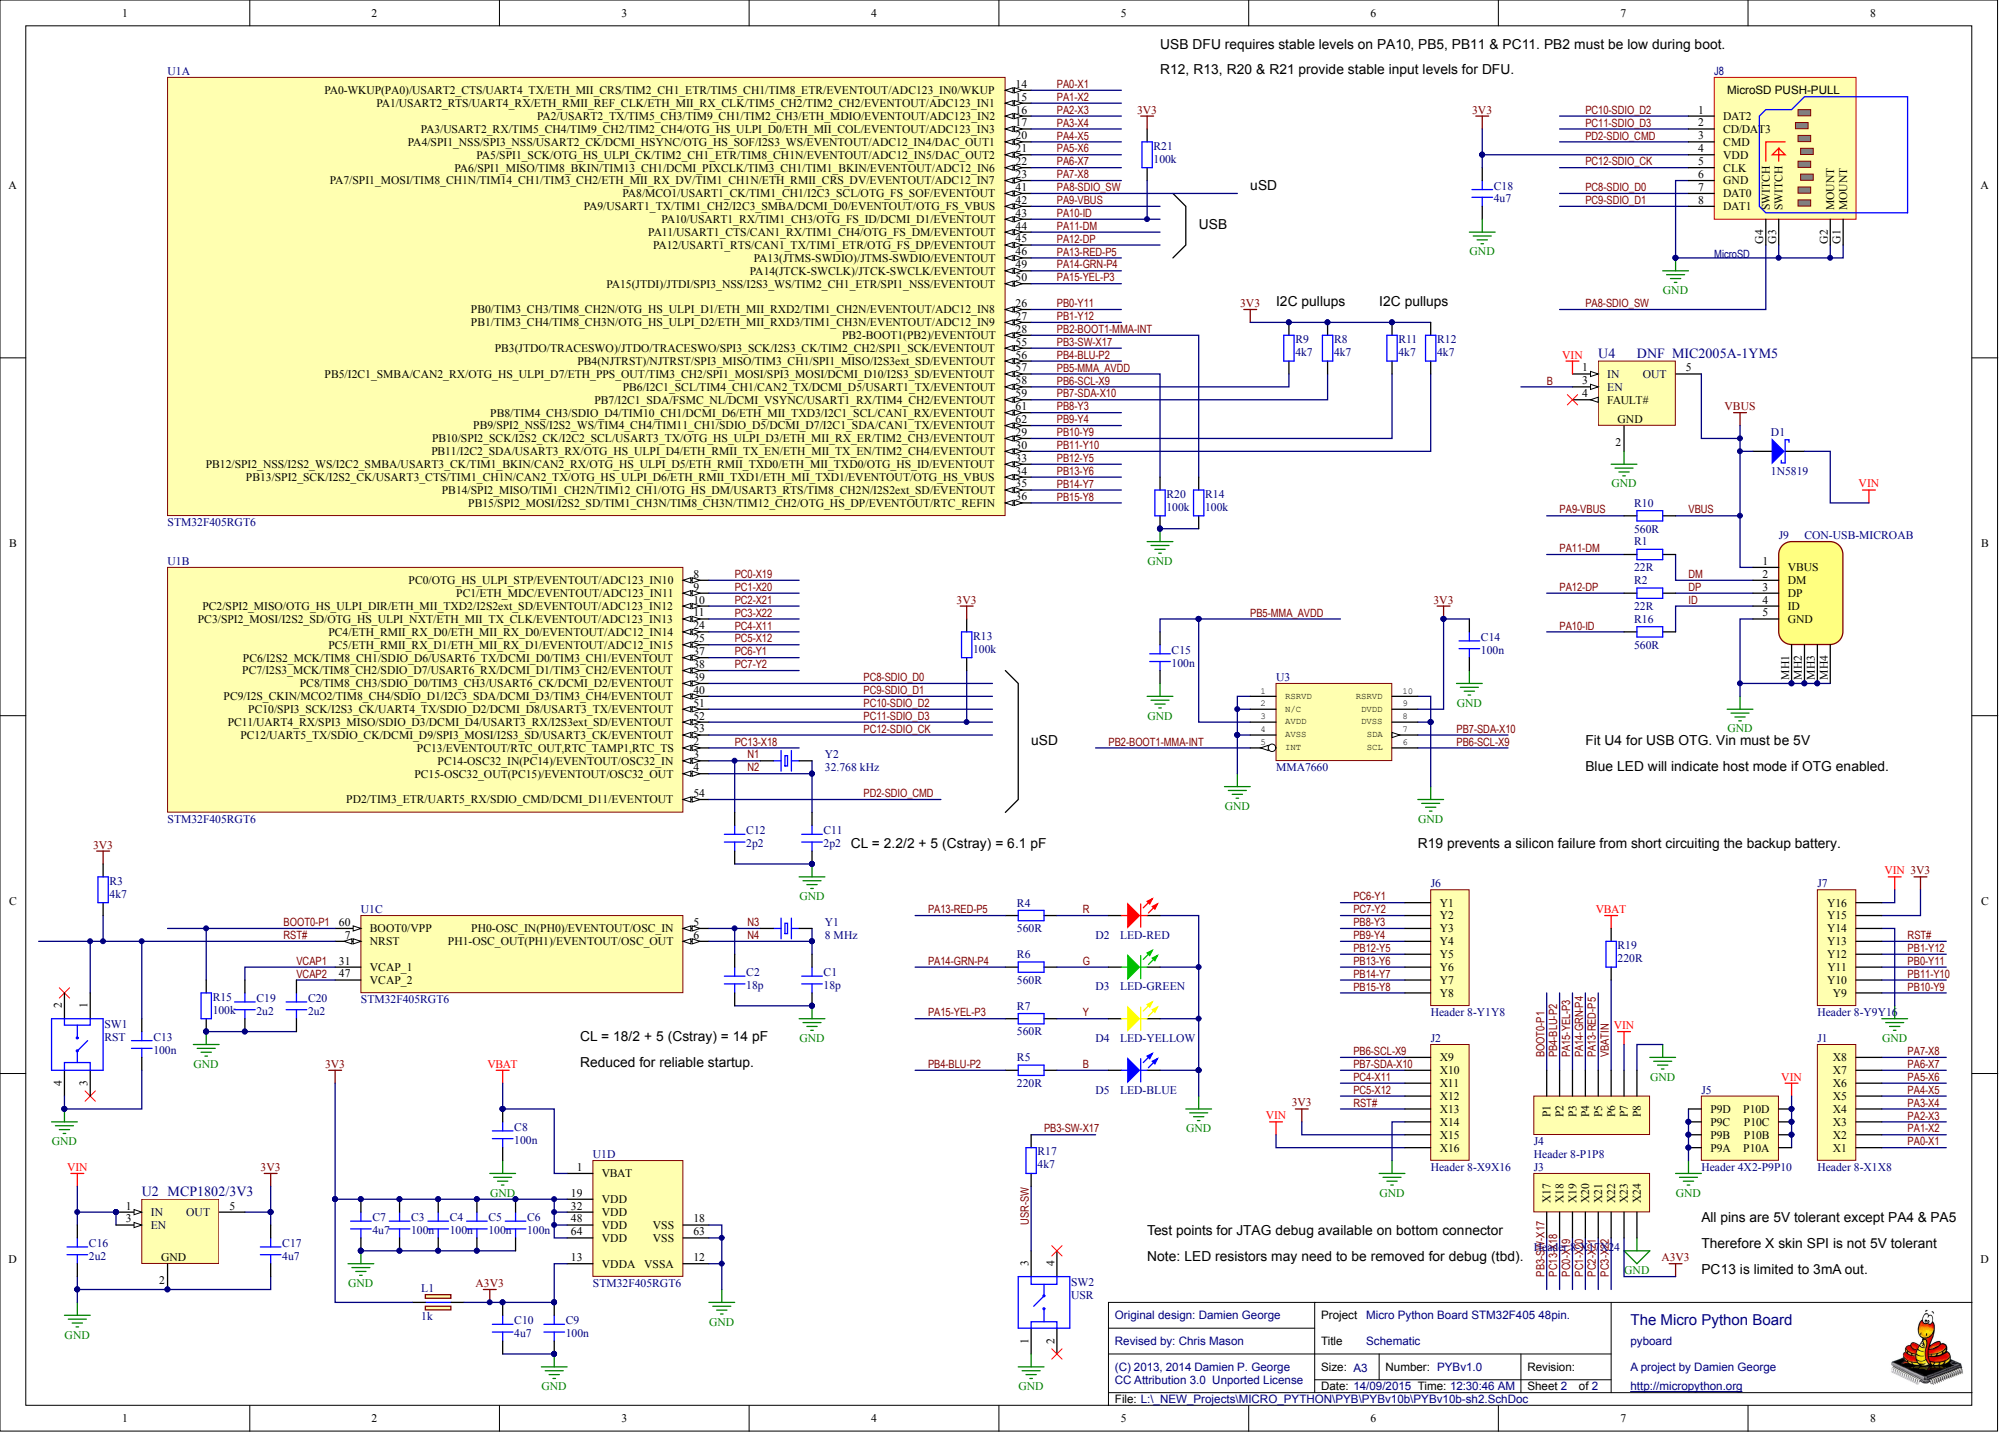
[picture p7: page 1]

D5 LED-BLUE USB DFU requires stable levels on PA10, PB5, PB11 & PC

11. PB2 must be low during boot.

R12, R13, R20 & R21 provide stable input levels for DFU

PB11-Y10
PB12-Y5 PB13-Y6

Fit U4 for USB OTG. Vin must be 5V

Blue LED will indicate host mode if OTG enabled.

GND
R19 prevents a silicon failure from short circuiting the backup battery

Reduced for reliable startup.

All pins are 5V tolerant except PA4 & PA5

Test points for JTAG debug available on bottom connector Note: LED resistors may need to be removed for debug (tbd).

Therefore X skin SPI is not 5V tolerant

Original design: Damien George

Project Micro Python Board STM32F405 48pin.

The Micro Python Board

Revised by: Chris Mason
L:\_NEW_Projects\MICRO_PYTHON\PYB\PYBv10b\PYBv10b-sh2.SchDoc Title

(C) 2013, 2014 Damien P. George
CC Attribution 3.0 Unported License
File:

A project by Damien George

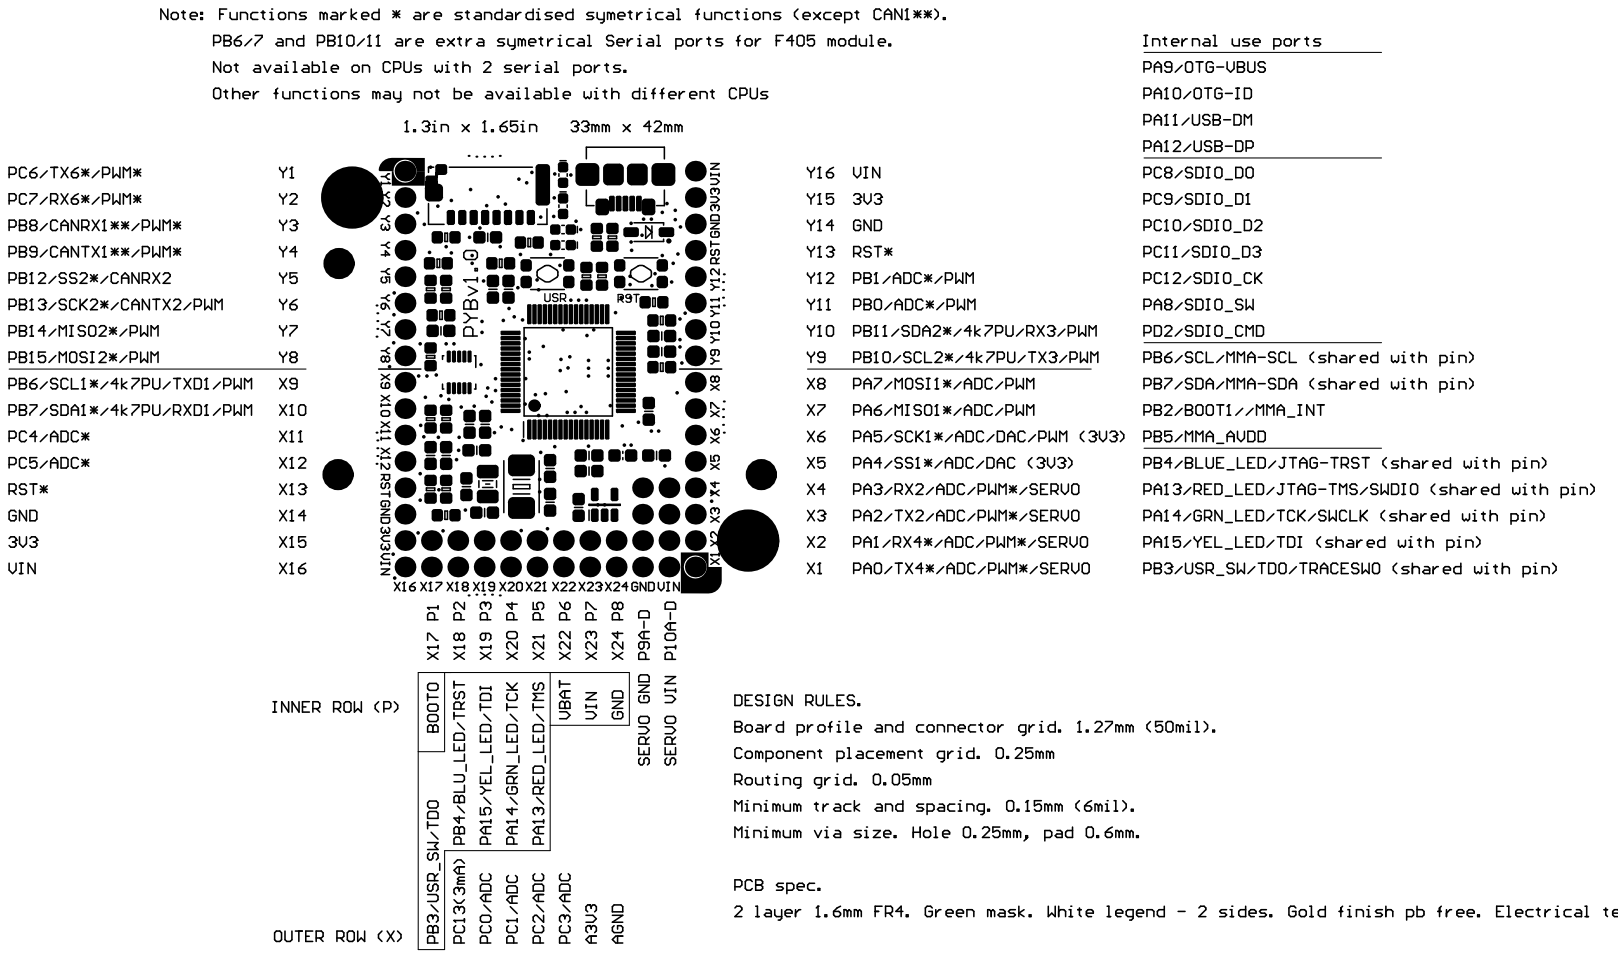
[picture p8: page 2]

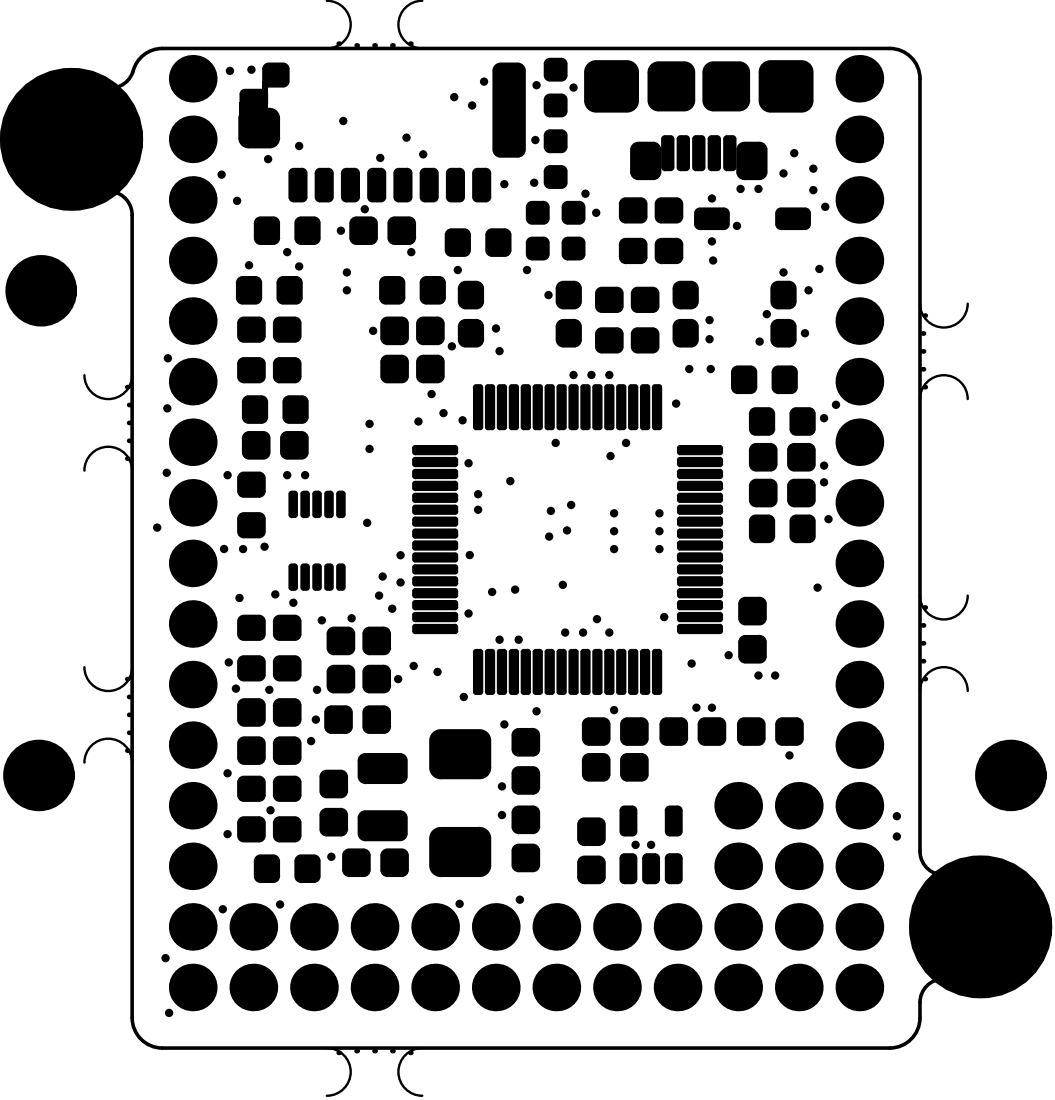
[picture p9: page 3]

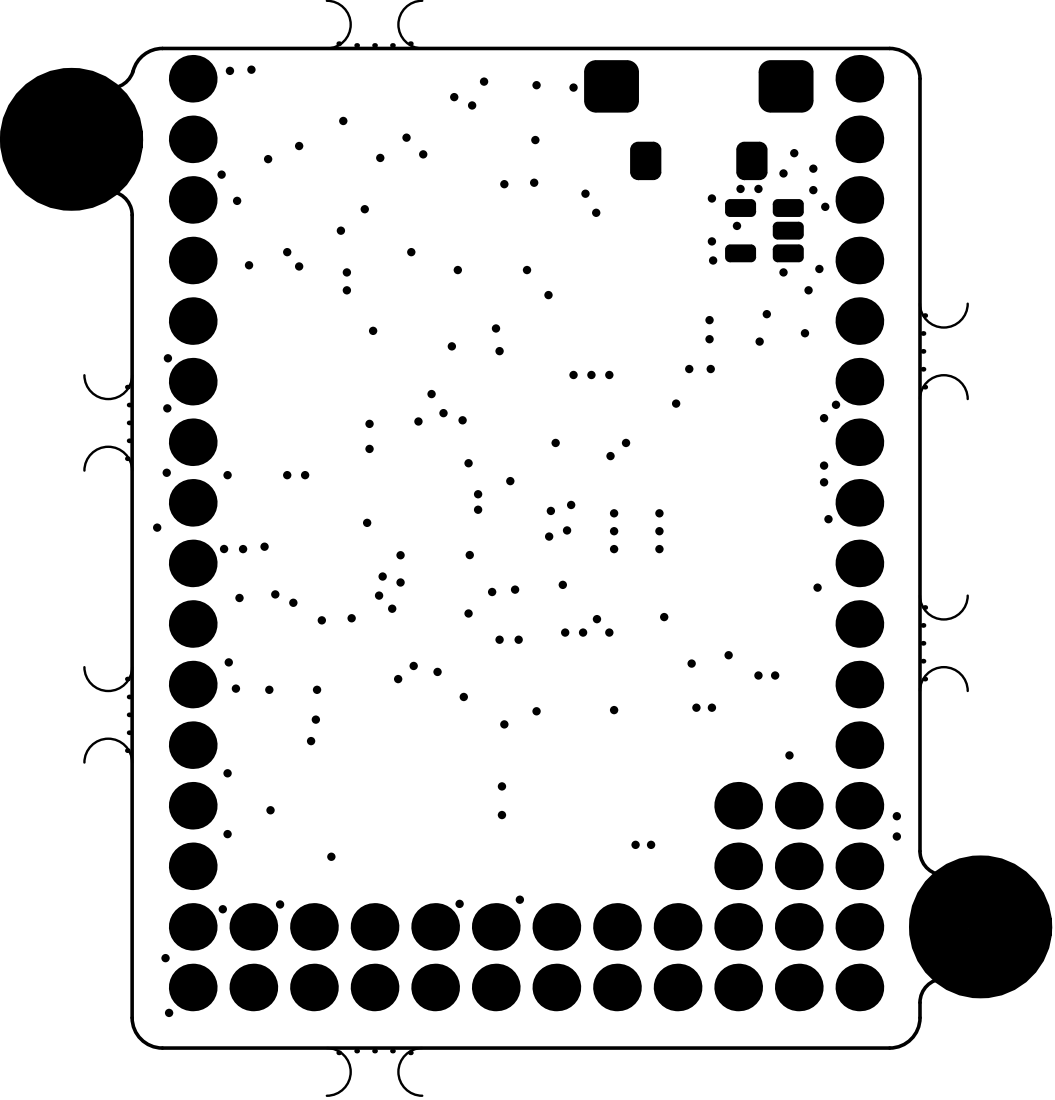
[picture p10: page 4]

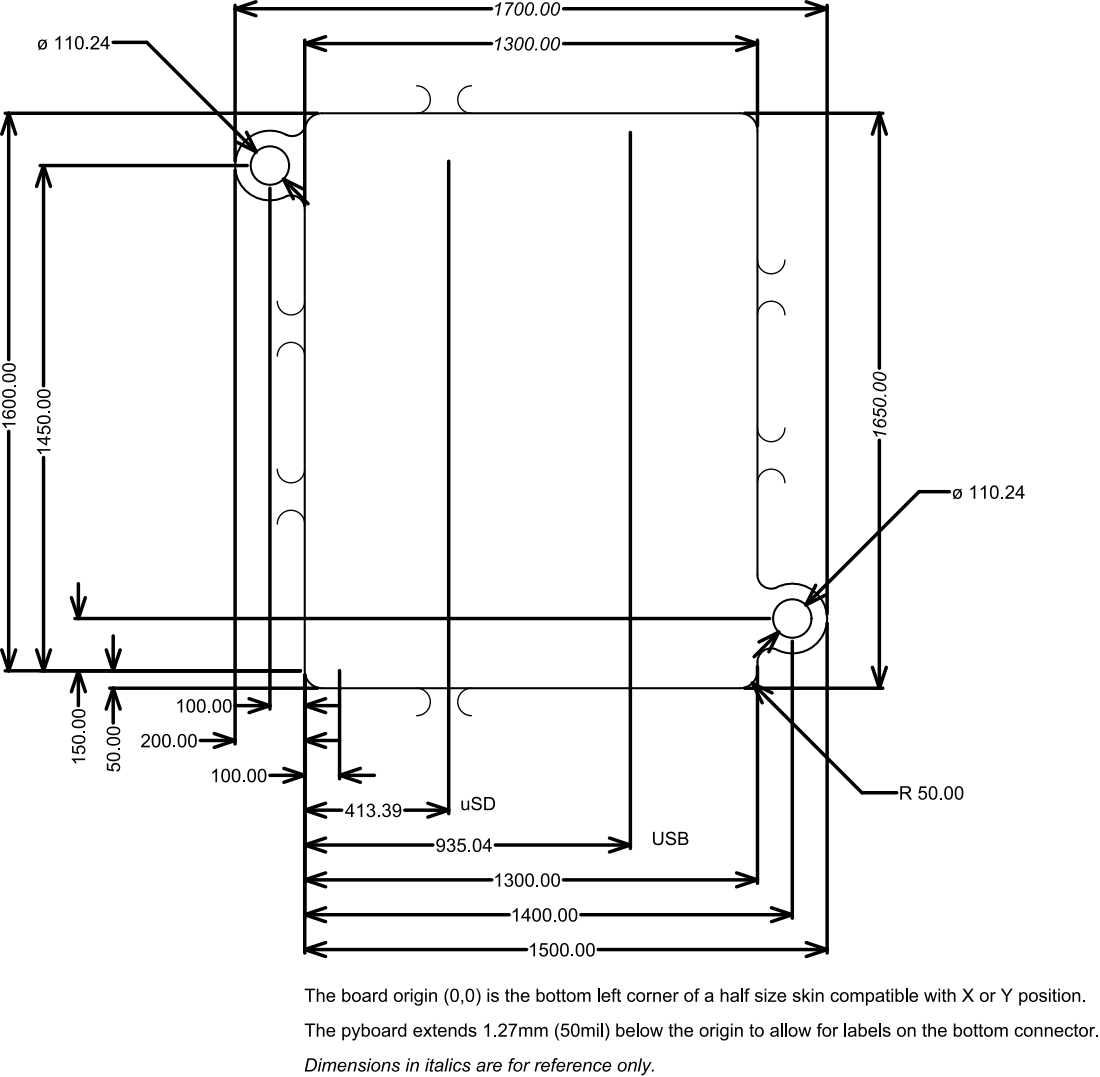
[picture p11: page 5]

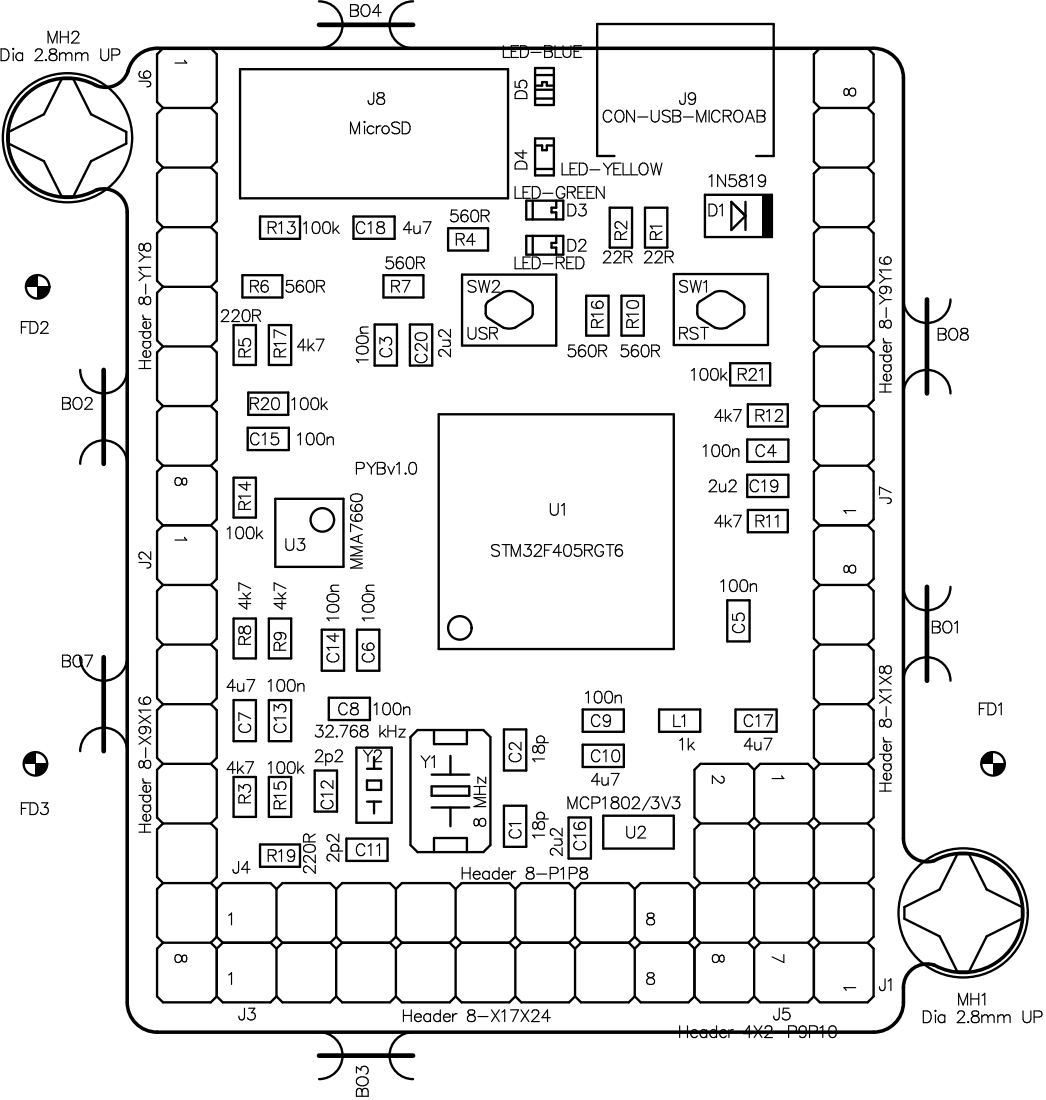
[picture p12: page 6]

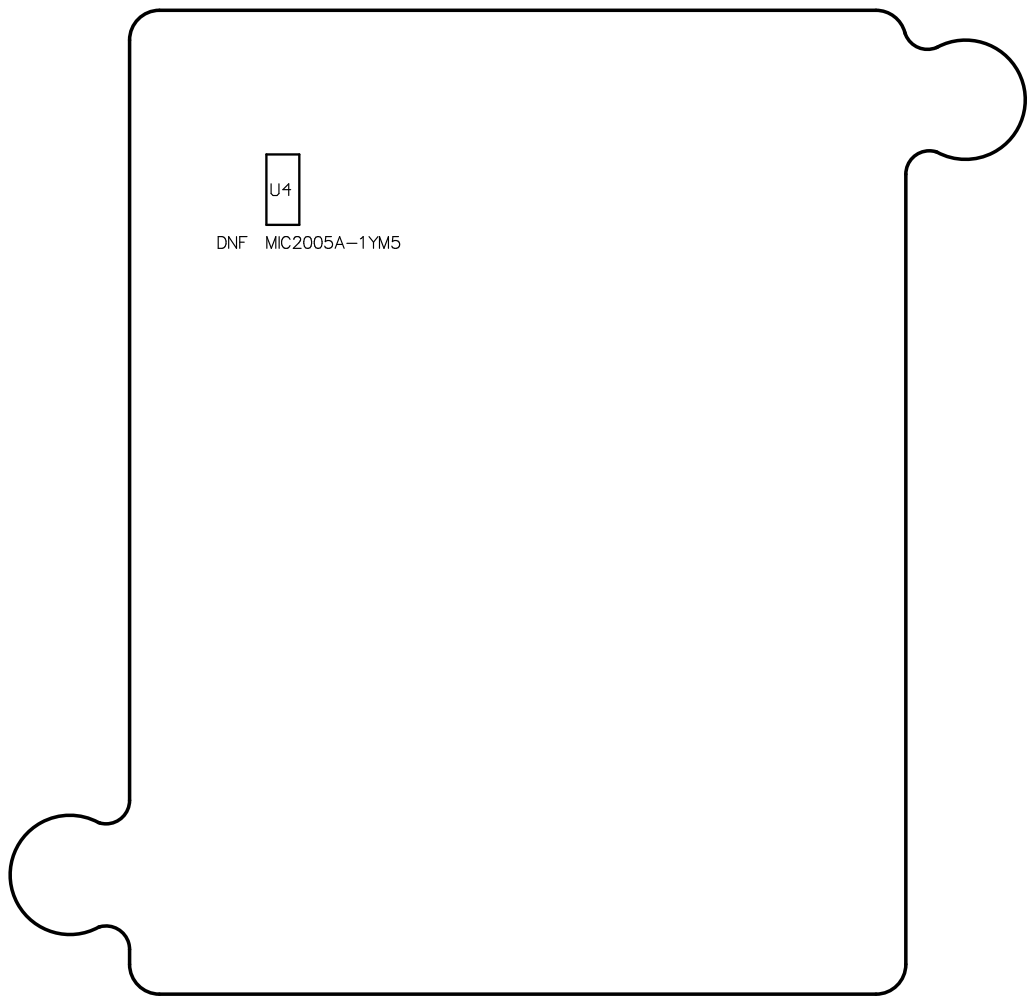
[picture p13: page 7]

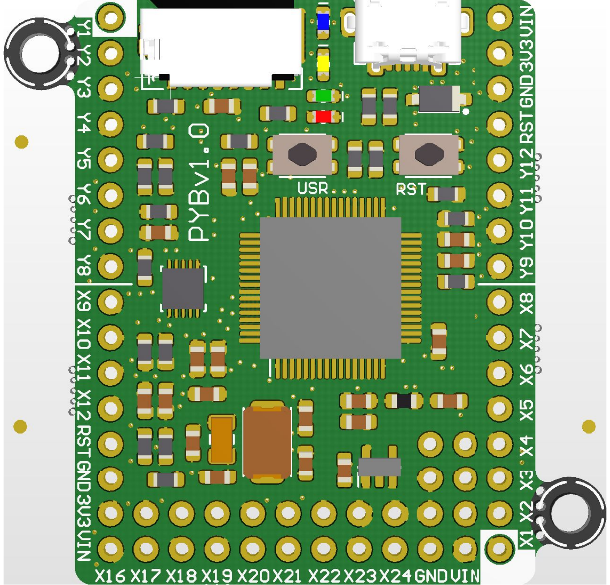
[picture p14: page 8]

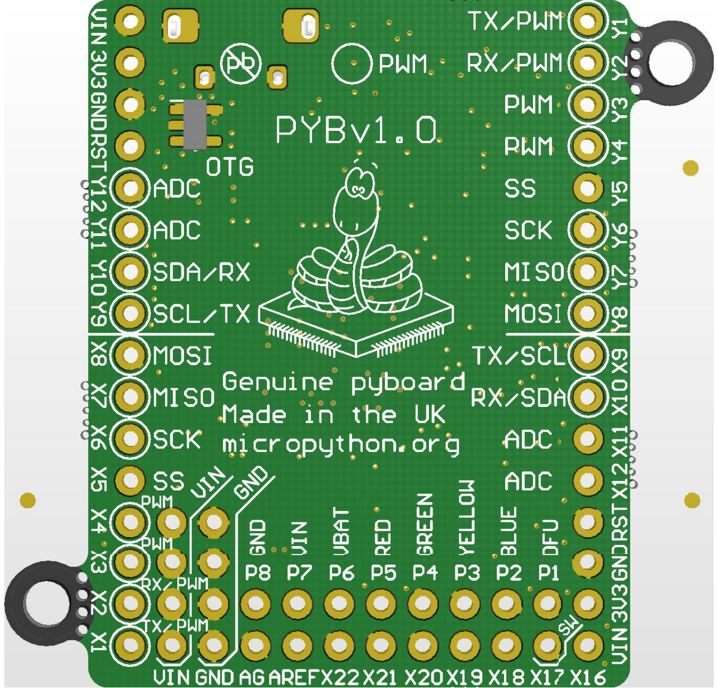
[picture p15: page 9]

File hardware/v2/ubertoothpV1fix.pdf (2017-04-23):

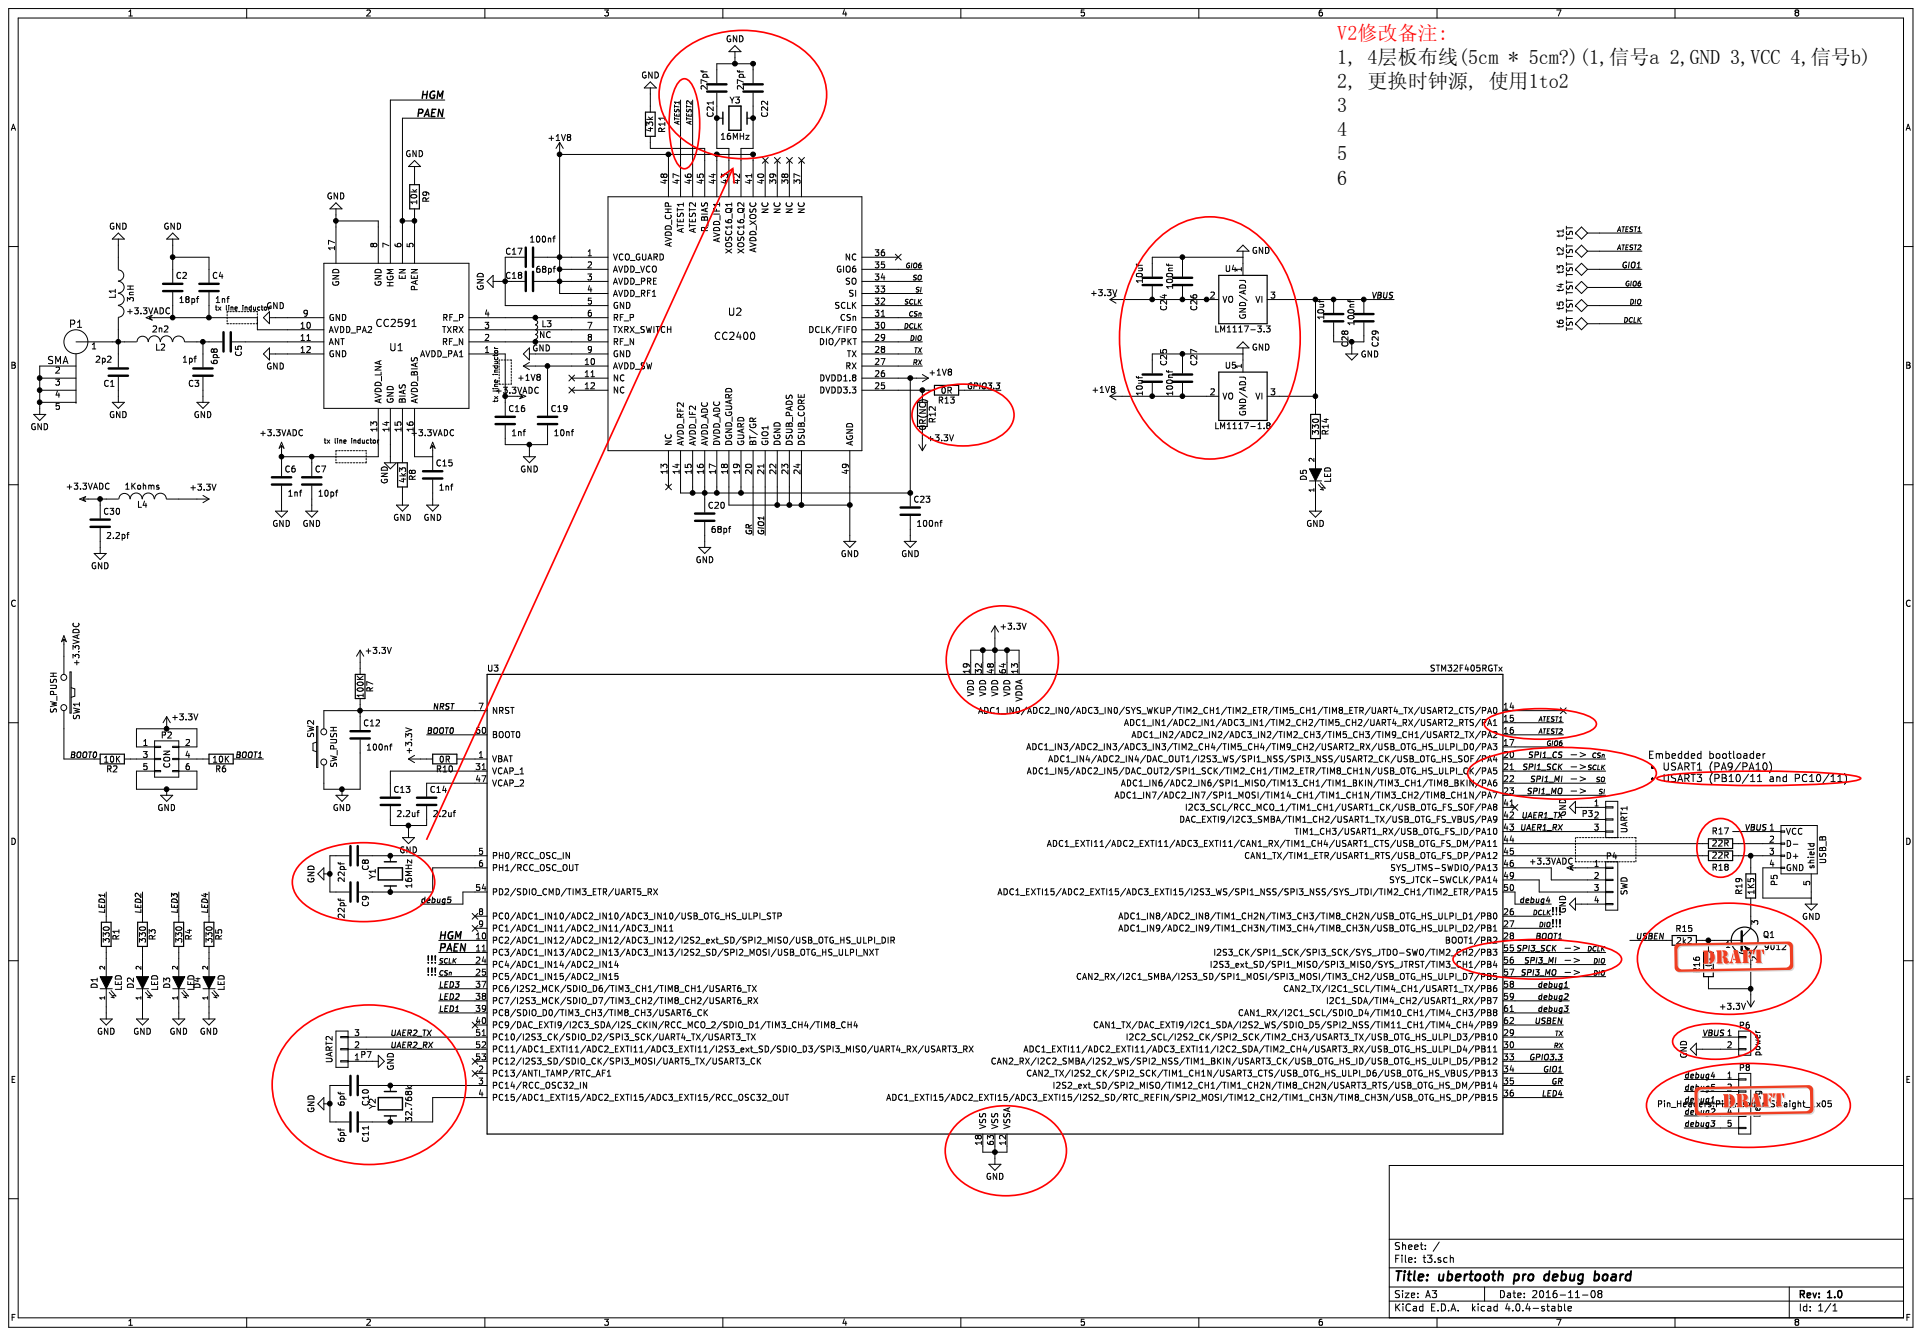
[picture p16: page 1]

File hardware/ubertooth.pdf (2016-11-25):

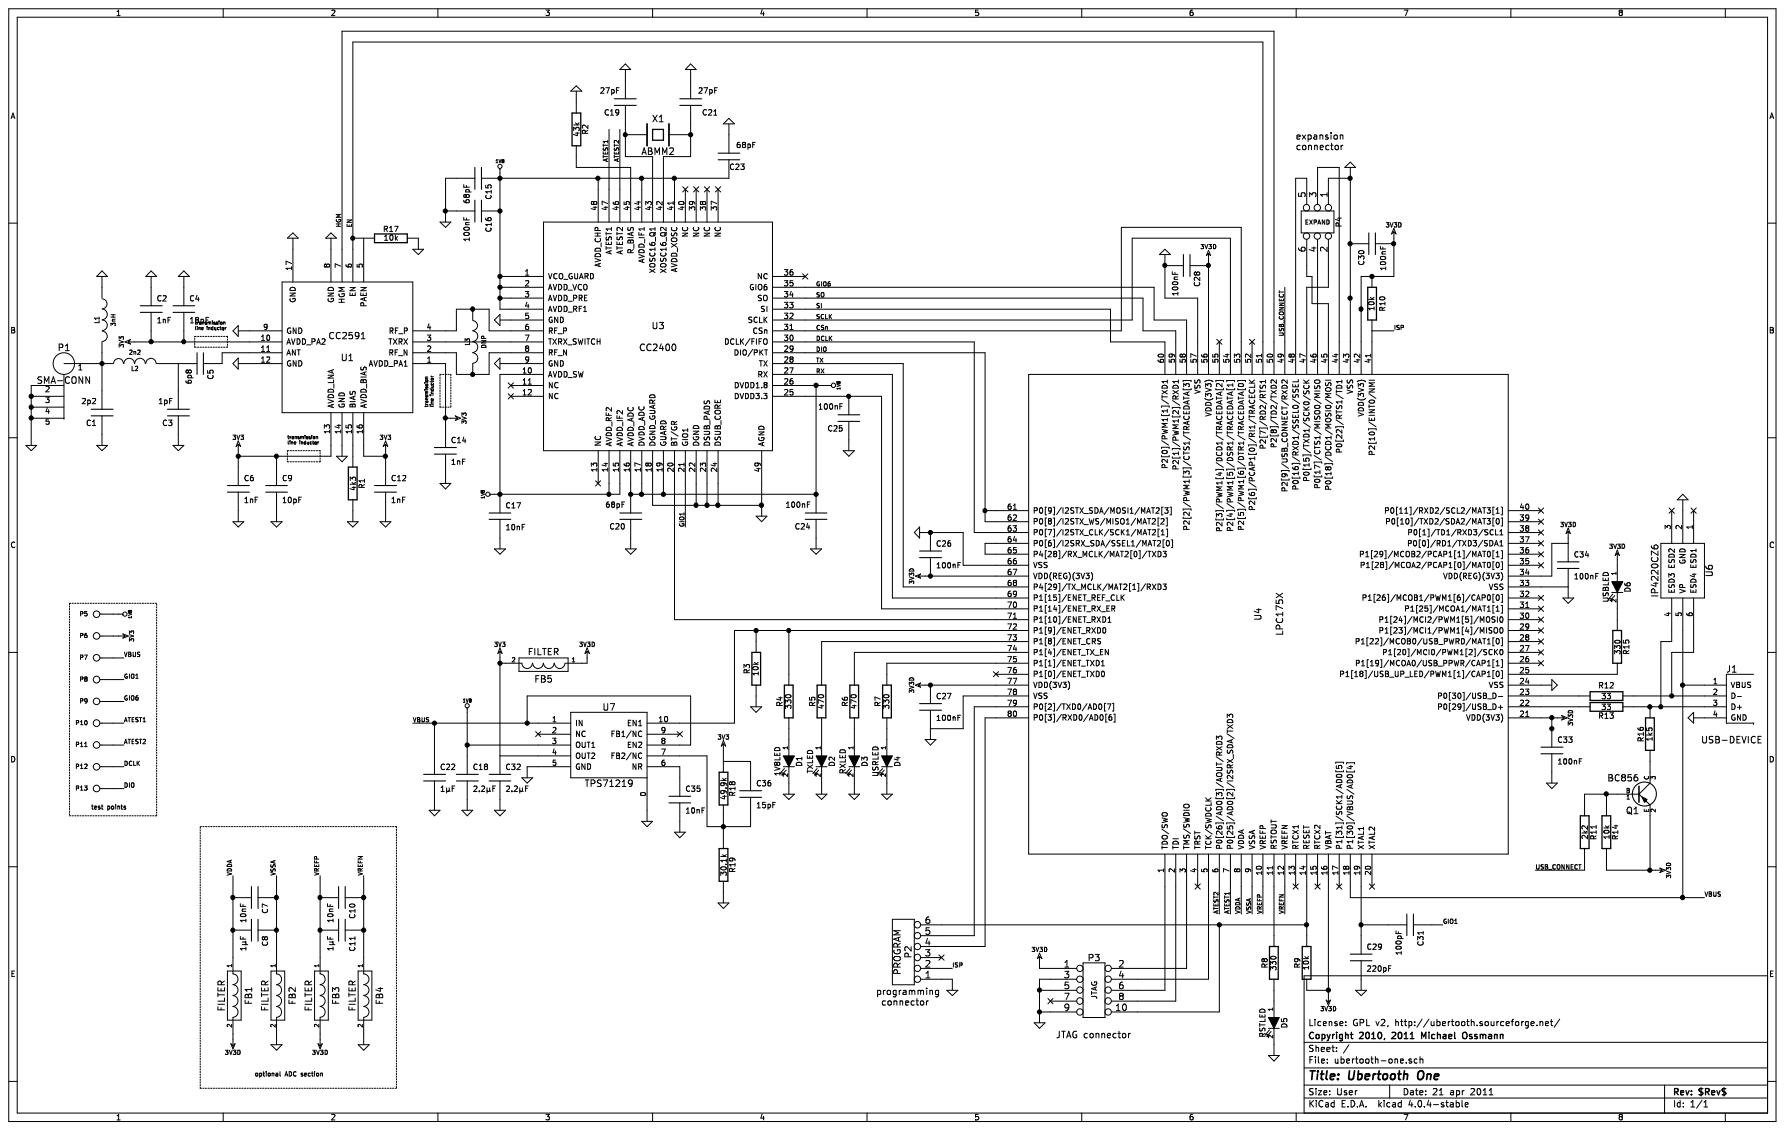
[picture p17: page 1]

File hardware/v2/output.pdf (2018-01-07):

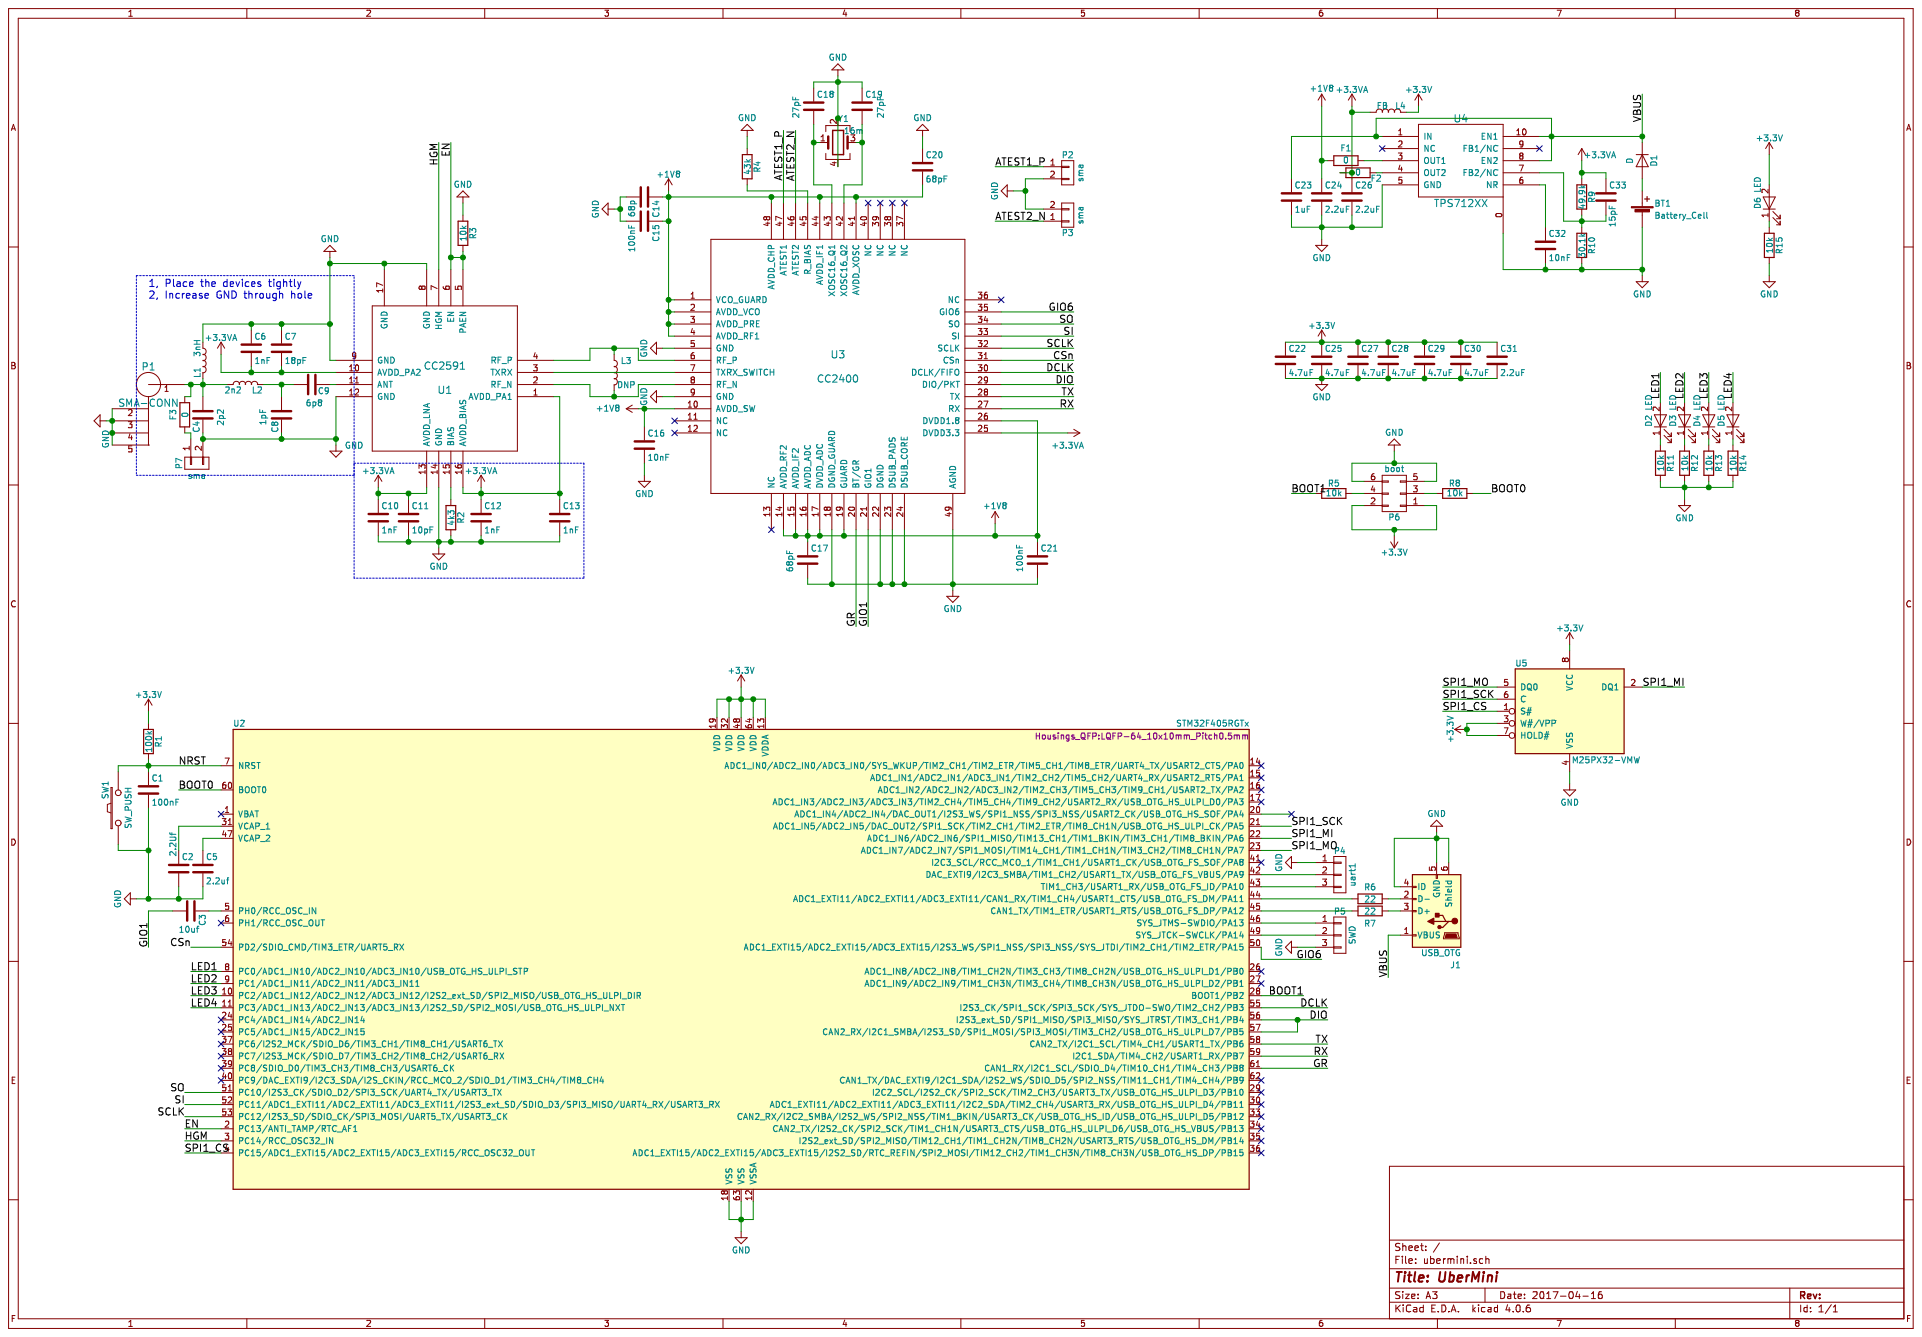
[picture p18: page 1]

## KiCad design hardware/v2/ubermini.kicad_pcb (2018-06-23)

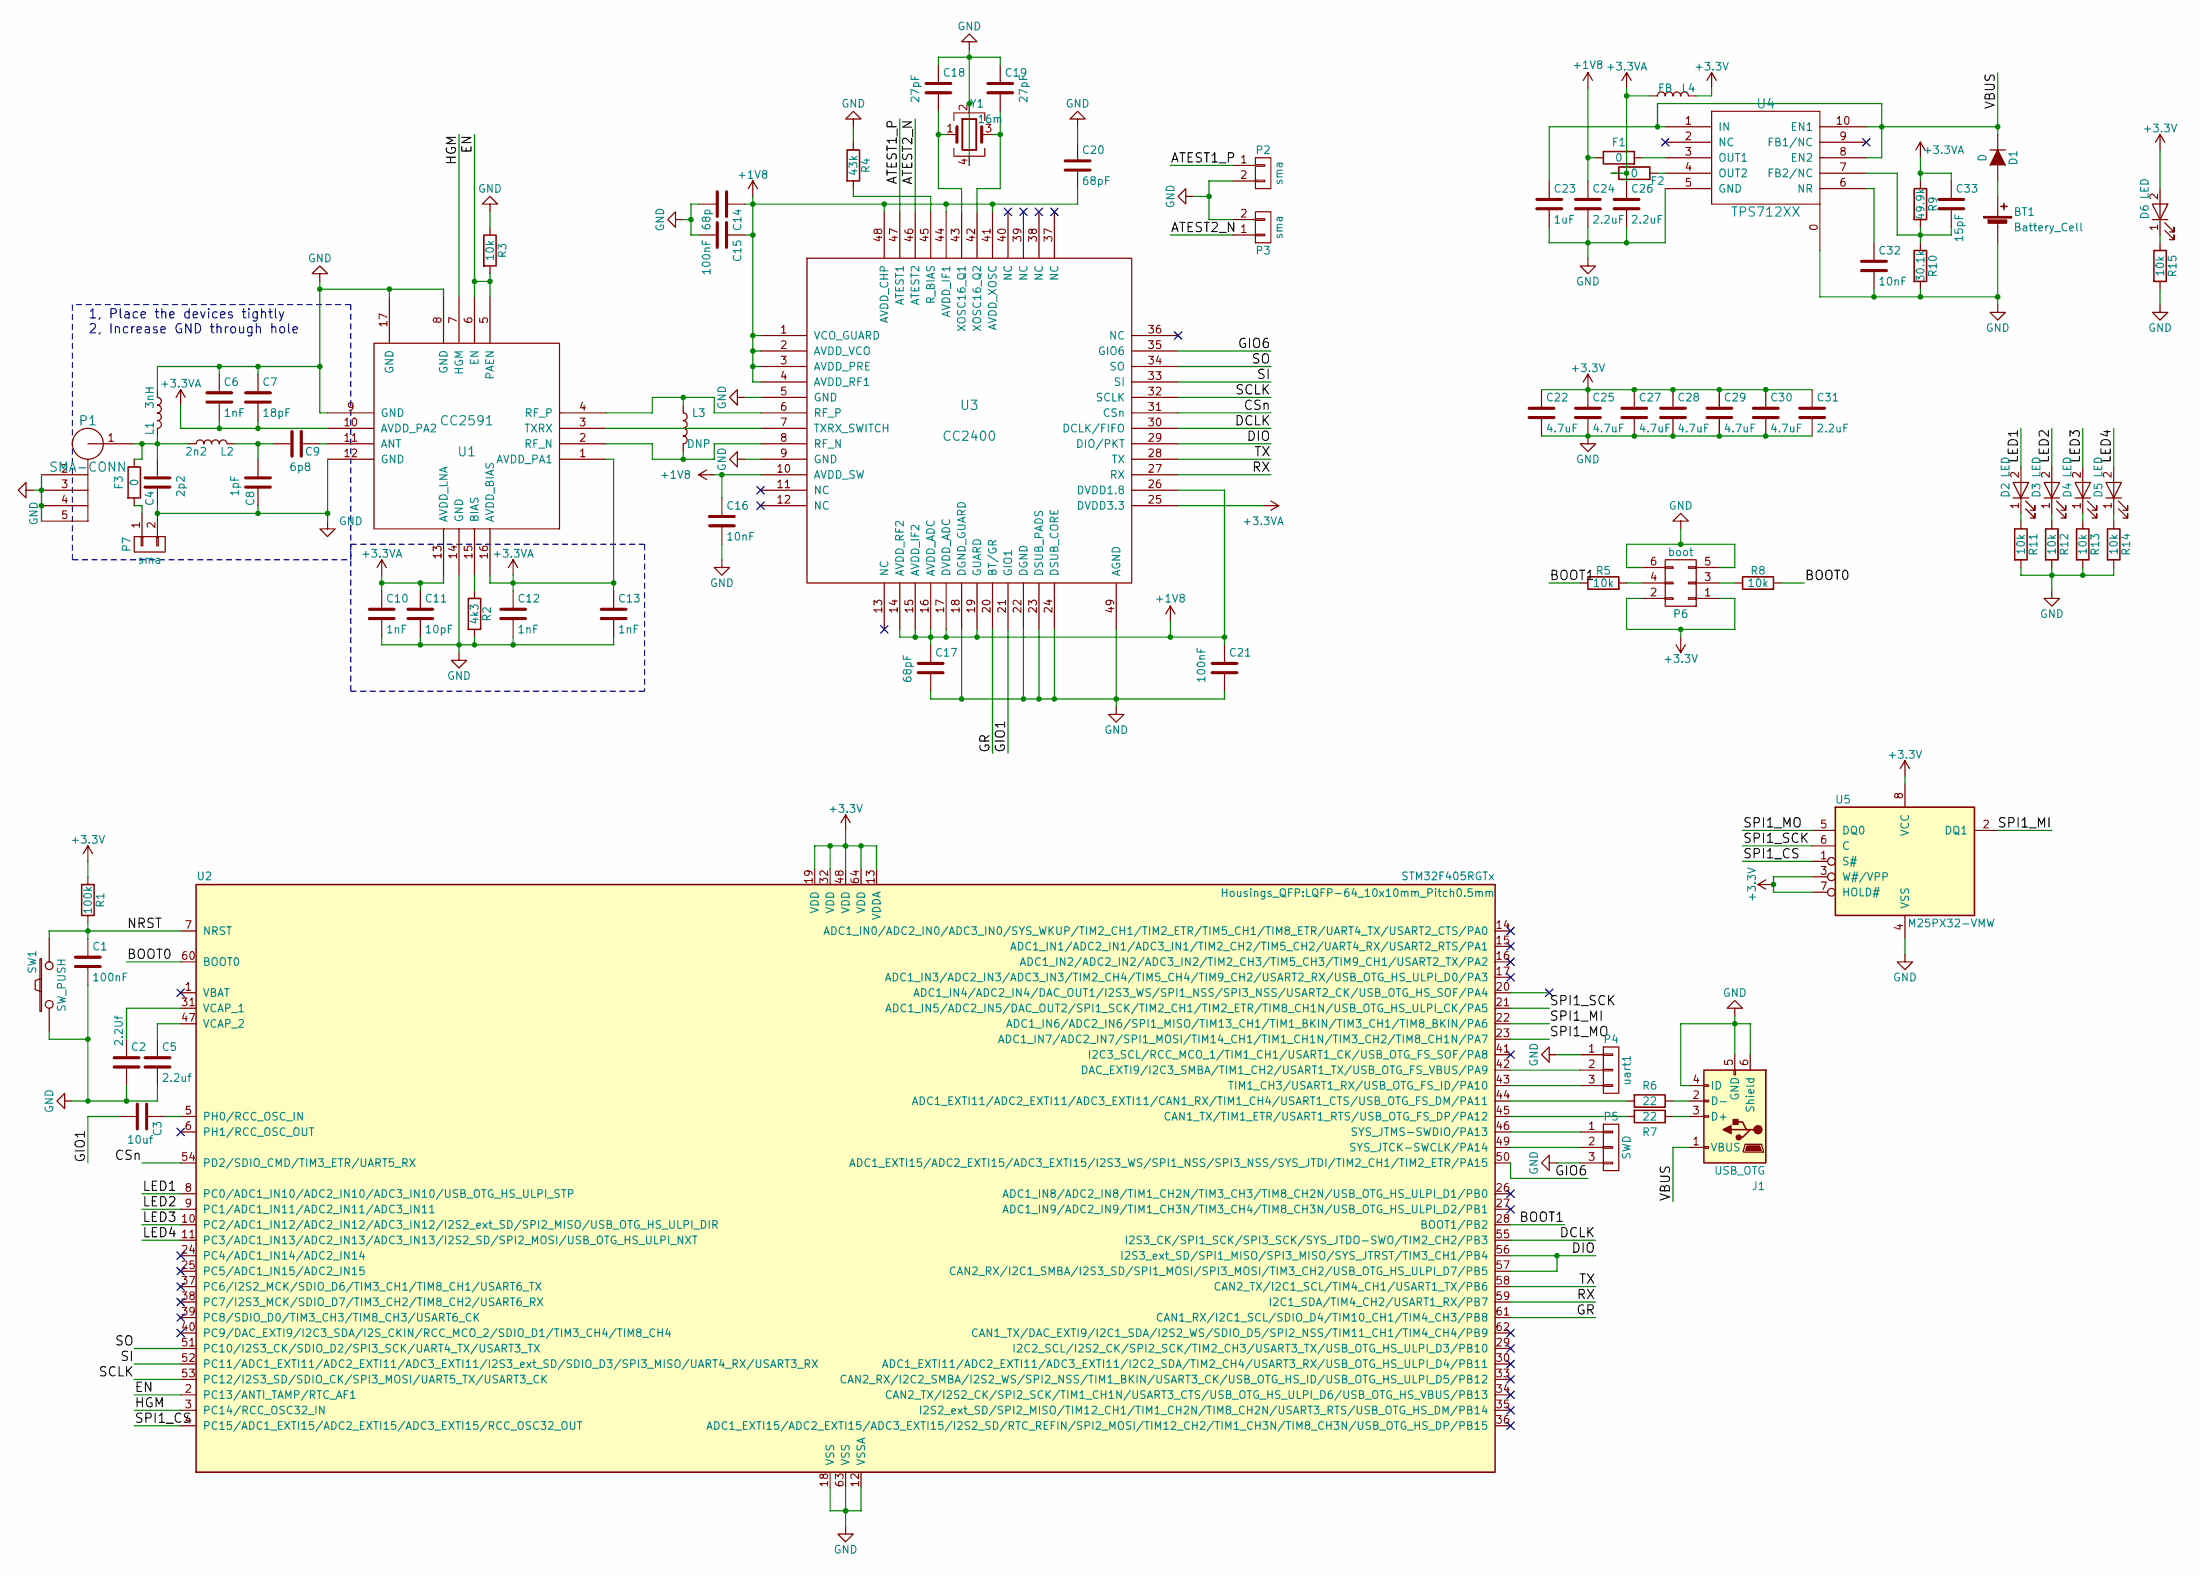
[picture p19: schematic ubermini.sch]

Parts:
BT1: Battery_Cell; Pin_Header_Straight_1x02
C1, C15, C21: 100nF; C_0603_HandSoldering
C2: 2.2Uf; C_0603_HandSoldering
C3: 10uf; C_0603_HandSoldering
C4: 2p2; C_0402
C5: 2.2uf; C_0603_HandSoldering
C6, C10, C12, C13: 1nF; C_0603_HandSoldering
C7: 18pF; C_0603_HandSoldering
C8: 1pF; C_0402
C9: 6p8; C_0402
C11: 10pF; C_0603_HandSoldering
C14: 68p; C_0603_HandSoldering
C16, C32: 10nF; C_0603_HandSoldering
C17, C20: 68pF; C_0603_HandSoldering
C18, C19: 27pF; C_0603_HandSoldering
C22, C25, C27, C28, C29, C30: 4.7uF; C_0603_HandSoldering
C23: 1uF; C_0603_HandSoldering
C24, C26, C31: 2.2uF; C_0603_HandSoldering
C33: 15pF; C_0603_HandSoldering
D1: D; R_0805_HandSoldering
D2, D3, D4, D5, D6: LED; LED_0805
F1, F2, F3: 0; C_0201
J1: USB_OTG; USB_Mini-B_s
L1: 3nH; C_0603
L2: 2n2; C_0603
L3: DNP; C_0402
L4: FB; C_0603_HandSoldering
P1: SMA-CONN; sma
P2, P3, P7: sma; U.FL
P4: uart1; Pin_Header_Straight_1x03
P5: SWD; Pin_Header_Straight_1x03
P6: boot; Pin_Header_Straight_2x03
R1: 100k; R_0603_HandSoldering
R2: 4k3; R_0603_HandSoldering
R3, R5, R8, R11, R12, R13, R14, R15: 10k; R_0603_HandSoldering
R4: 43k; R_0603_HandSoldering
R6, R7: 22; R_0603_HandSoldering
R9: 49.9k; R_0603_HandSoldering
R10: 30.1k; R_0603_HandSoldering
SW1: SW_PUSH; SW_SPST_FSMSM
U1: CC2591; cc2591
U2: STM32F405RGTx; LQFP-64_10x10mm_Pitch0.5mm
U3: CC2400; cc2400
U4: TPS712XX; tps712
U5: M25PX32-VMW; winband_spi_flash
Y1: 16m; 3225

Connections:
+1V8: C14.1, C15.1, C16.1, C17.1, C20.2, C21.1, C24.1, F1.1, U3.1 (VCO_GUARD), U3.2 (AVDD_VCO), U3.3 (AVDD_PRE), U3.4 (AVDD_RF1), U3.10 (AVDD_SW), U3.14 (AVDD_RF2), U3.15 (AVDD_IF2), U3.16 (AVDD_ADC), U3.17 (DVDD_ADC), U3.19 (GUARD), U3.26 (DVDD1.8), U3.41 (AVDD_XOSC), U3.44 (AVDD_IF1), U3.48 (AVDD_CHP)
+3.3VA: C6.2, C7.2, C10.1, C11.1, C12.1, C13.1, C26.1, C33.1, F2.1, L4.1, R9.1, U1.1 (AVDD_PA1), U1.10 (AVDD_PA2), U1.13 (AVDD_LNA), U1.16 (AVDD_BIAS), U3.25 (DVDD3.3)
+3V3: C22.1, C25.1, C27.1, C28.1, C29.1, C30.1, C31.1, D6.2 (A), L4.2, P6.1, P6.2, R1.1, U2.13 (VDDA), U2.19 (VDD), U2.32 (VDD), U2.48 (VDD), U2.64 (VDD), U5.3 (W#/VPP), U5.7 (HOLD#), U5.8 (VCC)
/ATEST1_P: P2.1, U3.47 (ATEST1)
/ATEST2_N: P3.1, U3.46 (ATEST2)
/BOOT0: R8.2, U2.60 (BOOT0)
/BOOT1: R5.1, U2.28 (BOOT1/PB2)
/CSn: U2.54 (PD2/SDIO_CMD/TIM3_ETR/UART5_RX), U3.31 (CSn)
/DCLK: U2.55 (I2S3_CK/SPI1_SCK/SPI3_SCK/SYS_JTDO-SWO/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), U3.30 (DCLK/FIFO)
/DIO: U2.56 (I2S3_ext_SD/SPI1_MISO/SPI3_MISO/SYS_JTR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), U2.57 (CAN2_RX/I2C1_SMBA/I2S3_SD/SPI1_MOSI/SPI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), U3.29 (DIO/PKT)
/EN: R3.2, U1.5 (PAEN), U1.6 (EN), U2.2 (PC13/ANTI_TAMP/RTC_AF1)
/GIO1: C3.2, U3.21 (GIO1)
/GIO6: U2.50 (ADC1_EXTI15/ADC2_EXTI15/ADC3_EXTI15/I2S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), U3.35 (GIO6)
/GR: U2.61 (CAN1_RX/I2C1_SCL/SDIO_D4/TIM10_CH1/TIM4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), U3.20 (BT/GR)
/HGM: U1.7 (HGM), U2.3 (PC14/RCC_OSC32_IN)
/LED1: D2.2 (A), U2.8 (PC0/ADC1_IN10/ADC2_IN10/ADC3_IN10/USB_O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)
/LED2: D3.2 (A), U2.9 (PC1/ADC1_IN11/ADC2_IN11/ADC3_IN11)
/LED3: D4.2 (A), U2.10 (PC2/ADC1_IN12/ADC2_IN12/ADC3_IN12/I2S2_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)
/LED4: D5.2 (A), U2.11 (PC3/ADC1_IN13/ADC2_IN13/ADC3_IN13/I2S2_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)
/NRST: C1.1, R1.2, SW1.2, U2.7 (NRST)
/RX: U2.59 (I2C1_SDA/TIM4_CH2/USART1_RX/PB7), U3.27 (RX)
/SCLK: U2.53 (PC12/I2S3_SD/SDIO_CK/SPI3_MOSI/UART5_TX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), U3.32 (SCLK)
/SI: U2.52 (PC11/ADC1_EXTI11/ADC2_EXTI11/ADC3_EXTI1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), U3.33 (SI)
/SO: U2.51 (PC10/I2S3_CK/SDIO_D2/SPI3_SCK/UART4_TX/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), U3.34 (SO)
/SPI1_CS: U2.4 (PC15/ADC1_EXTI15/ADC2_EXTI15/ADC3_EXTI1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), U5.1 (S#)
/SPI1_MI: U2.22 (ADC1_IN6/ADC2_IN6/SPI1_MISO/TIM13_CH1/T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), U5.2 (DQ1)
/SPI1_MO: U2.23 (ADC1_IN7/ADC2_IN7/SPI1_MOSI/TIM14_CH1/T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), U5.5 (DQ0)
/SPI1_SCK: U2.21 (ADC1_IN5/ADC2_IN5/DAC_OUT2/SPI1_SCK/TIM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), U5.6 (C)
/TX: U2.58 (CAN2_TX/I2C1_SCL/TIM4_CH1/USART1_TX/PB6), U3.28 (TX)
/VBUS: C23.1, D1.1 (K), J1.1 (VBUS), U4.1 (IN), U4.8 (EN2), U4.10 (EN1)
GND: BT1.2 (-), C1.2, C2.2, C4.1, C5.2, C6.1, C7.1, C8.1, C10.2, C11.2, C12.2, C13.2, C14.2, C15.2, C16.2, C17.2, C18.1, C19.1, C20.1, C21.2, C22.2, C23.2, C24.2, C25.2, C26.2, C27.2, C28.2, C29.2, C30.2, C31.2, C32.2, J1.4 (ID), J1.5 (GND), J1.6 (Shield), L1.1, P1.2 (GND), P1.3 (GND), P1.4 (GND), P1.5 (GND), P2.2, P3.2, P4.1, P5.3, P6.5, P6.6, P7.2, R2.2, R3.1, R4.1, R10.2, R11.2, R12.2, R13.2, R14.2, R15.2, SW1.1, U1.8 (GND), U1.9 (GND), U1.12 (GND), U1.14 (GND), U1.17 (GND), U2.12 (VSSA), U2.18 (VSS), U2.63 (VSS), U3.5 (GND), U3.9 (GND), U3.18 (DGND_GUARD), U3.22 (DGND), U3.23 (DSUB_PADS), U3.24 (DSUB_CORE), U3.49 (AGND), U4.0, U4.5 (GND), U5.4 (VSS), Y1.2, Y1.4
unnamed: BT1.1 (+), D1.2 (A)
unnamed: C2.1, U2.31 (VCAP_1)
unnamed: C3.1, U2.5 (PH0/RCC_OSC_IN)
unnamed: C4.2, F3.1, L1.2, L2.1, P1.1 (RF)
unnamed: C5.1, U2.47 (VCAP_2)
unnamed: C8.2, C9.2, L2.2
unnamed: C9.1, U1.11 (ANT)
unnamed: C18.2, U3.43 (XOSC16_Q1), Y1.1
unnamed: C19.2, U3.42 (XOSC16_Q2), Y1.3
unnamed: C32.1, U4.6 (NR)
unnamed: C33.2, R9.2, R10.1, U4.7 (FB2/NC)
unnamed: D2.1 (K), R11.1
unnamed: D3.1 (K), R12.1
unnamed: D4.1 (K), R13.1
unnamed: D5.1 (K), R14.1
unnamed: D6.1 (K), R15.1
unnamed: F1.2, U4.3 (OUT1)
unnamed: F2.2, U4.4 (OUT2)
unnamed: F3.2, P7.1
unnamed: J1.2 (D-), R6.1
unnamed: J1.3 (D+), R7.1
unnamed: L3.1, U1.4 (RF_P), U3.6 (RF_P)
unnamed: L3.2, U1.2 (RF_N), U3.8 (RF_N)
unnamed: P4.2, U2.42 (DAC_EXTI9/I2C3_SMBA/TIM1_CH2/USART1_TX/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)
unnamed: P4.3, U2.43 (TIM1_CH3/USART1_RX/USB_OTG_FS_ID/PA10)
unnamed: P5.1, U2.46 (SYS_JTMS-SWDIO/PA13)
unnamed: P5.2, U2.49 (SYS_JTCK-SWCLK/PA14)
unnamed: P6.3, R8.1
unnamed: P6.4, R5.2
unnamed: R2.1, U1.15 (BIAS)
unnamed: R4.2, U3.45 (R_BIAS)
unnamed: R6.2, U2.44 (ADC1_EXTI11/ADC2_EXTI11/ADC3_EXTI11/CAN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)
unnamed: R7.2, U2.45 (CAN1_TX/TIM1_ETR/USART1_RTS/USB_OTG_FS_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)
unnamed: U1.3 (TXRX), U3.7 (TXRX_SWITCH)

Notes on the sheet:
1, Place the devices tightly 2, Increase GND through hole

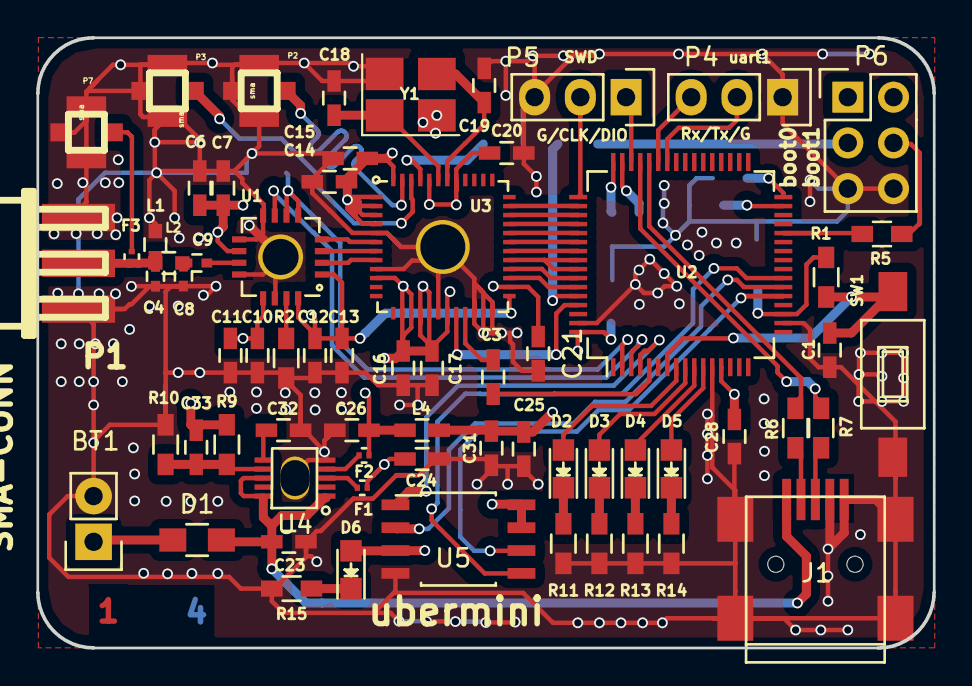
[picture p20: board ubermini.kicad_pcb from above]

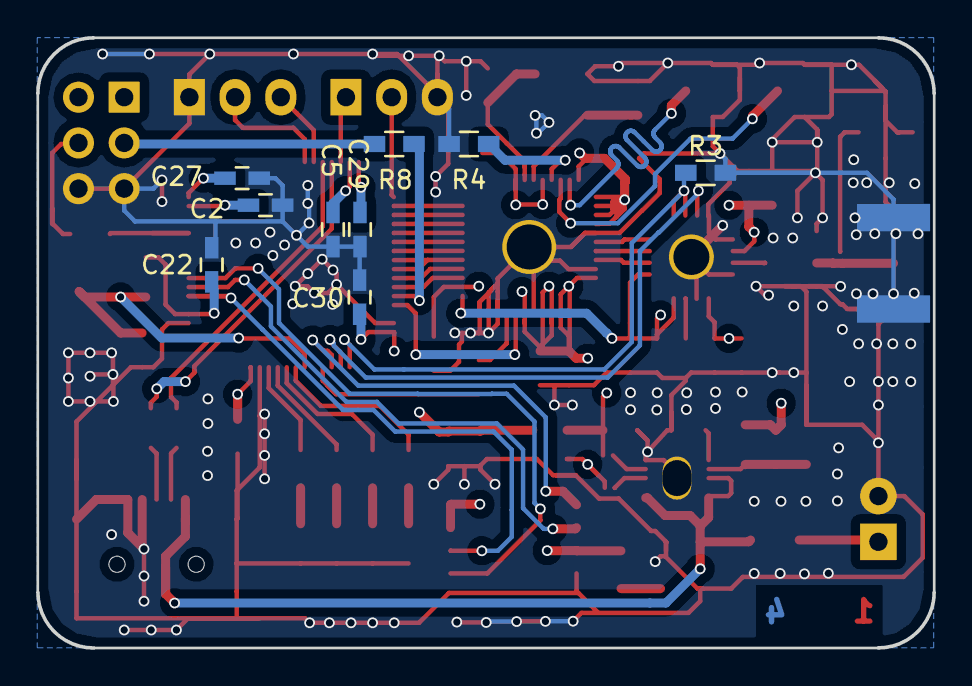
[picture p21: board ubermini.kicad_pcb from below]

Board: 4 copper layers, 49.8 x 33.9 mm, 76 parts (9 on the bottom side), 65 nets.

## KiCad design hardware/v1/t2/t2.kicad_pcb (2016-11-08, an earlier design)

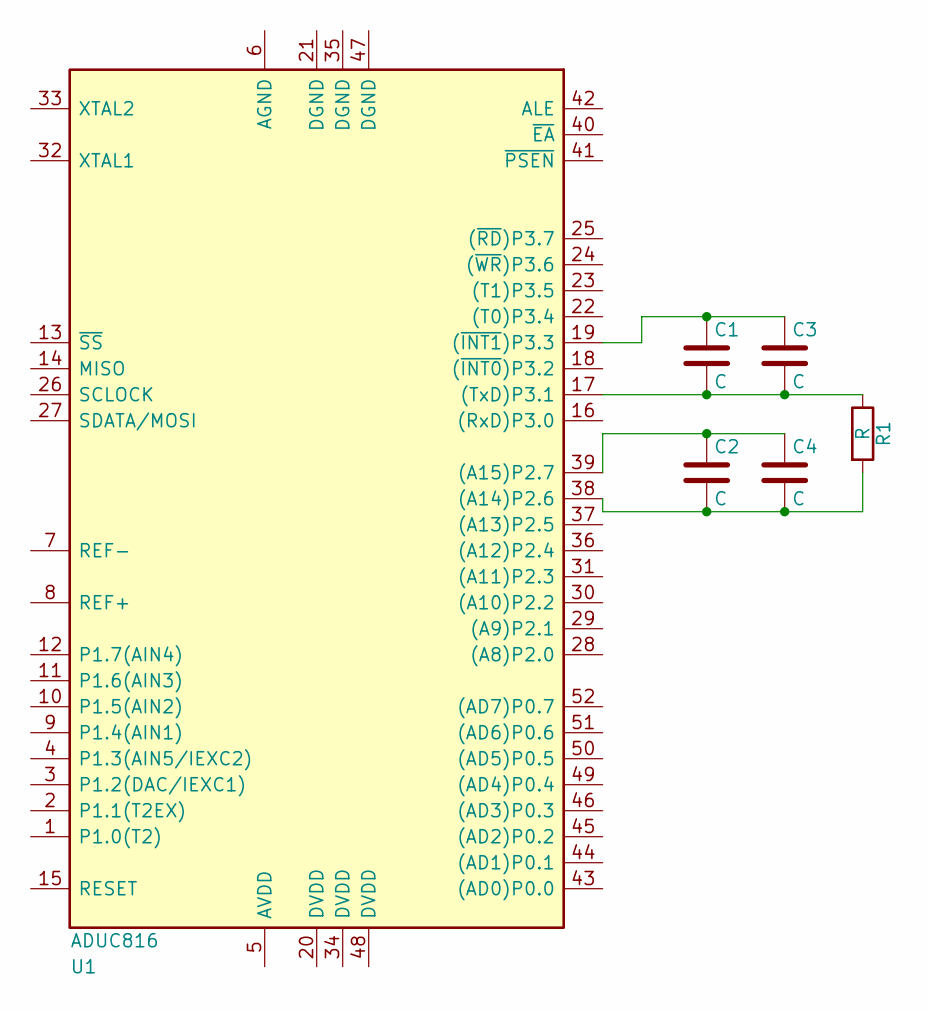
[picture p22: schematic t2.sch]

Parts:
C1, C2: C; C_0402
C3, C4: C; C_0603
R1: R; C_0603
U1: ADUC816; LQFP-52_10x10mm_Pitch0.65mm

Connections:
unnamed: C1.1, C3.1, U1.19 ((~INT1~)P3.3)
unnamed: C1.2, C3.2, R1.1, U1.17 ((TxD)P3.1)
unnamed: C2.1, C4.1, U1.39 ((A15)P2.7)
unnamed: C2.2, C4.2, R1.2, U1.38 ((A14)P2.6)

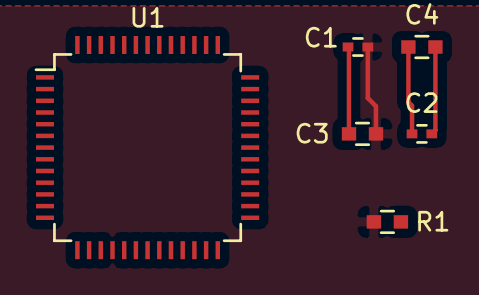
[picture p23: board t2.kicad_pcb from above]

Board: 2 copper layers, 6 parts (0 on the bottom side), 4 nets.

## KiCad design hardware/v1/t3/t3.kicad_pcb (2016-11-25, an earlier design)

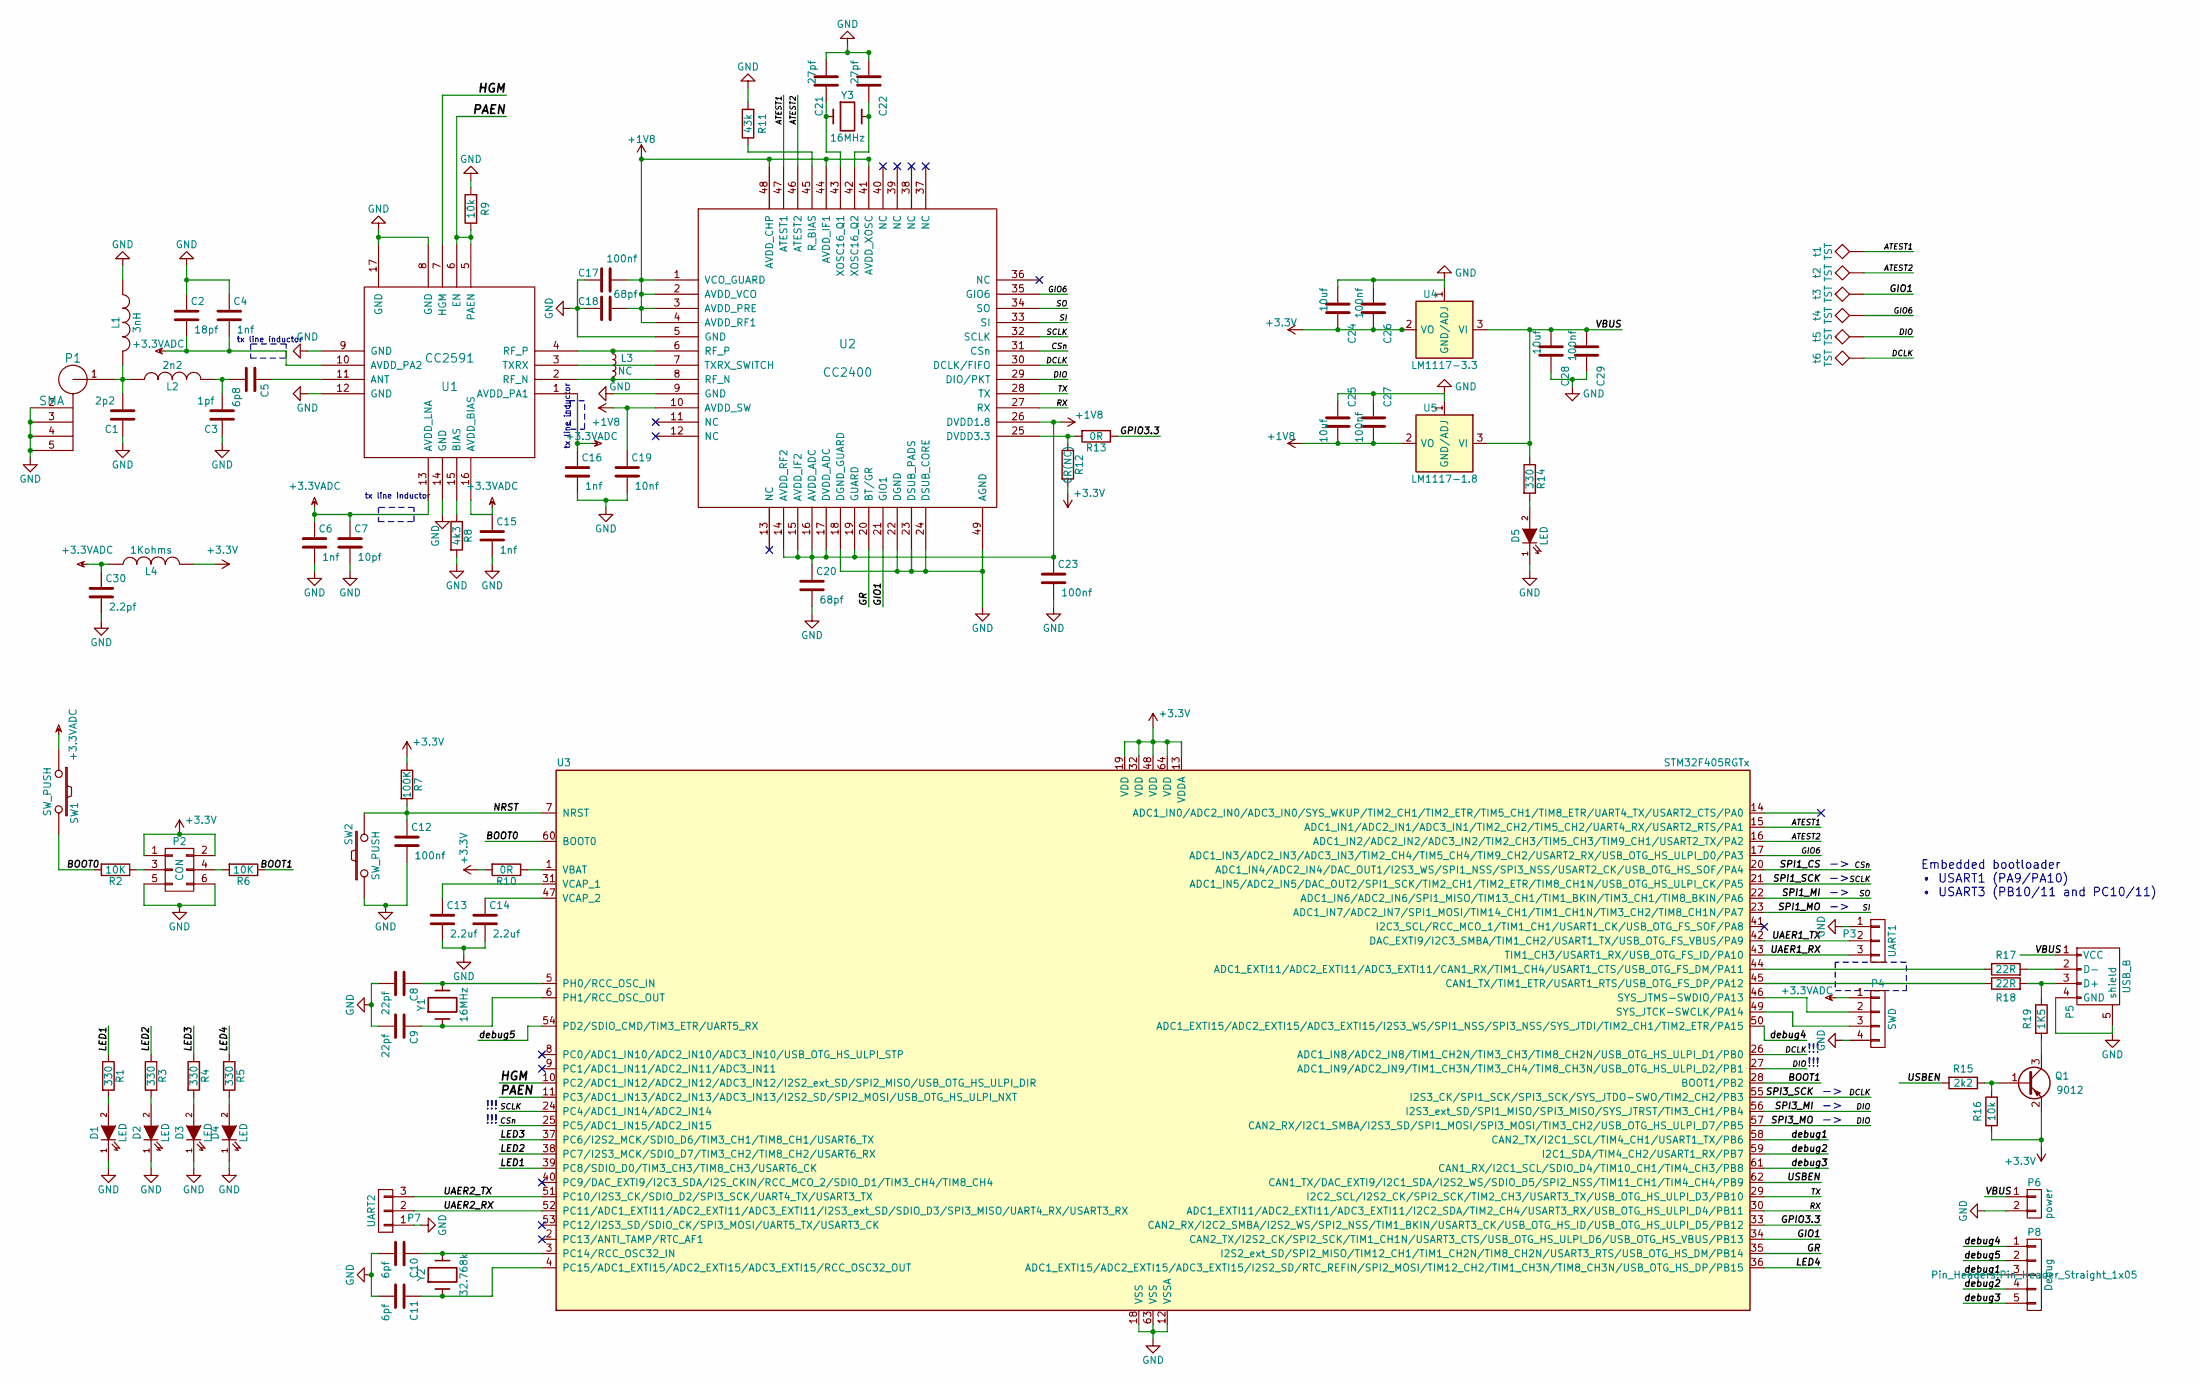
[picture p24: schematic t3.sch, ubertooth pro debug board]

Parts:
C1: 2p2; C_0603_HandSoldering
C2: 18pf; C_0603_HandSoldering
C3: 1pf; C_0603_HandSoldering
C4, C6: 1nf; C_0805_HandSoldering
C5: 6p8; C_0603_HandSoldering
C7: 10pf; C_0603_HandSoldering
C8, C9: 22pf; C_0603_HandSoldering
C10, C11: 6pf; C_0603_HandSoldering
C12, C26, C27, C29: 100nf; C_0603_HandSoldering
C13, C14: 2.2uf; C_0603_HandSoldering
C15, C16: 1nf; C_0603_HandSoldering
C17, C23: 100nf; C_0805_HandSoldering
C18, C20: 68pf; C_0603_HandSoldering
C19: 10nf; C_0603_HandSoldering
C21, C22: 27pf; C_0603_HandSoldering
C24, C25, C28: 10uf; C_0805_HandSoldering
C30: 2.2pf; C_0603_HandSoldering
D1, D2, D3, D4, D5: LED; C_0603_HandSoldering
L1: 3nH; C_0603_HandSoldering
L2: 2n2; C_0603_HandSoldering
L3: NC; C_0603_HandSoldering
L4: 1Kohms; C_0603_HandSoldering
P1: SMA; lemo_epb00250ntn
P2: CON; Pin_Header_Straight_2x03
P3: UART1; Pin_Header_Straight_1x03
P4: SWD; Pin_Header_Straight_1x04
P5: USB_B; USB_Mini-B
P6: power; Pin_Header_Straight_1x02
P7: UART2; Pin_Header_Straight_1x03
P8: Debug; Pin_Header_Straight_1x05
Q1: 9012; SOT-23
R1, R3, R4, R5, R14: 330; C_0603_HandSoldering
R2, R6: 10K; C_0603_HandSoldering
R7: 100K; C_0603_HandSoldering
R8: 4k3; C_0603_HandSoldering
R9, R16: 10k; C_0603_HandSoldering
R10, R13: 0R; C_0603_HandSoldering
R11: 43k; C_0603_HandSoldering
R12: 0R(NC); C_0603_HandSoldering
R15: 2k2; C_0603_HandSoldering
R17, R18: 22R; C_0603_HandSoldering
R19: 1K5; C_0603_HandSoldering
SW1, SW2: SW_PUSH; SW_SPST_EVQPE1
U1: CC2591; QFN-16-1EP_4x4mm_Pitch0.65mm
U2: CC2400; cc2400_Soldering
U3: STM32F405RGTx; LQFP-64_10x10mm_Pitch0.5mm
U4: LM1117-3.3; SOT-223
U5: LM1117-1.8; SOT-223
Y1, Y3: 16MHz; Crystal_HC49-U_Vertical
Y2: 32.768k; Crystal_Round_Horizontal_3mm
t1, t2, t3, t4, t5, t6: TST; test_pin

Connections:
+1V8: C17.1, C18.1, C19.1, C20.1, C23.1, C25.2, C27.2, U2.1 (VCO_GUARD), U2.2 (AVDD_VCO), U2.3 (AVDD_PRE), U2.4 (AVDD_RF1), U2.10 (AVDD_SW), U2.14 (AVDD_RF2), U2.15 (AVDD_IF2), U2.16 (AVDD_ADC), U2.17 (DVDD_ADC), U2.19 (GUARD), U2.26 (DVDD1.8), U2.41 (AVDD_XOSC), U2.44 (AVDD_IF1), U2.48 (AVDD_CHP), U5.2 (VO), U5.4 (VO)
+3.3VADC: C2.2, C4.2, C6.1, C7.1, C15.1, C16.1, C30.1, L4.1, P4.1, SW1.1, U1.1 (AVDD_PA1), U1.10 (AVDD_PA2), U1.13 (AVDD_LNA), U1.16 (AVDD_BIAS)
+3V3: C24.1, C26.1, L4.2, P2.1, P2.2, Q1.2 (E), R7.1, R10.2, R12.2, R16.2, U3.13 (VDDA), U3.19 (VDD), U3.32 (VDD), U3.48 (VDD), U3.64 (VDD), U4.2 (VO), U4.4 (VO)
/ATEST1: U2.47 (ATEST1), U3.15 (ADC1_IN1/ADC2_IN1/ADC3_IN1/TIM2_CH2/TIM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), t1.1
/ATEST2: U2.46 (ATEST2), U3.16 (ADC1_IN2/ADC2_IN2/ADC3_IN2/TIM2_CH3/TIM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), t2.1
/BOOT0: R2.2, SW1.2, U3.60 (BOOT0)
/BOOT1: R6.1, U3.28 (BOOT1/PB2)
/CSn: U2.31 (CSn), U3.20 (ADC1_IN4/ADC2_IN4/DAC_OUT1/I2S3_WS/SPI1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), U3.25 (PC5/ADC1_IN15/ADC2_IN15)
/DCLK: U2.30 (DCLK/FIFO), U3.26 (ADC1_IN8/ADC2_IN8/TIM1_CH2N/TIM3_CH3/TI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), U3.55 (I2S3_CK/SPI1_SCK/SPI3_SCK/SYS_JTDO-SWO/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), t6.1
/DIO: U2.29 (DIO/PKT), U3.27 (ADC1_IN9/ADC2_IN9/TIM1_CH3N/TIM3_CH4/TI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), U3.56 (I2S3_ext_SD/SPI1_MISO/SPI3_MISO/SYS_JTR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), U3.57 (CAN2_RX/I2C1_SMBA/I2S3_SD/SPI1_MOSI/SPI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), t5.1
/GIO1: U2.21 (GIO1), U3.34 (CAN2_TX/I2S2_CK/SPI2_SCK/TIM1_CH1N/USAR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), t3.1
/GIO6: U2.35 (GIO6), U3.17 (ADC1_IN3/ADC2_IN3/ADC3_IN3/TIM2_CH4/TIM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), t4.1
/GPIO3.3: R13.1, U3.33 (CAN2_RX/I2C2_SMBA/I2S2_WS/SPI2_NSS/TIM1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)
/GR: U2.20 (BT/GR), U3.35 (I2S2_ext_SD/SPI2_MISO/TIM12_CH1/TIM1_CH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)
/HGM: U1.7 (HGM), U3.10 (PC2/ADC1_IN12/ADC2_IN12/ADC3_IN12/I2S2_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)
/LED1: R1.1, U3.39 (PC8/SDIO_D0/TIM3_CH3/TIM8_CH3/USART6_CK)
/LED2: R3.1, U3.38 (PC7/I2S3_MCK/SDIO_D7/TIM3_CH2/TIM8_CH2/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)
/LED3: R4.1, U3.37 (PC6/I2S2_MCK/SDIO_D6/TIM3_CH1/TIM8_CH1/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)
/LED4: R5.1, U3.36 (ADC1_EXTI15/ADC2_EXTI15/ADC3_EXTI15/I2S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)
/NRST: C12.1, R7.2, SW2.2, U3.7 (NRST)
/PAEN: R9.1, U1.5 (PAEN), U1.6 (EN), U3.11 (PC3/ADC1_IN13/ADC2_IN13/ADC3_IN13/I2S2_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)
/RX: U2.27 (RX), U3.30 (ADC1_EXTI11/ADC2_EXTI11/ADC3_EXTI11/I2C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)
/SCLK: U2.32 (SCLK), U3.21 (ADC1_IN5/ADC2_IN5/DAC_OUT2/SPI1_SCK/TIM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), U3.24 (PC4/ADC1_IN14/ADC2_IN14)
/SI: U2.33 (SI), U3.23 (ADC1_IN7/ADC2_IN7/SPI1_MOSI/TIM14_CH1/T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)
/SO: U2.34 (SO), U3.22 (ADC1_IN6/ADC2_IN6/SPI1_MISO/TIM13_CH1/T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)
/TX: U2.28 (TX), U3.29 (I2C2_SCL/I2S2_CK/SPI2_SCK/TIM2_CH3/USAR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)
/UAER1_RX: P3.3, U3.43 (TIM1_CH3/USART1_RX/USB_OTG_FS_ID/PA10)
/UAER1_TX: P3.2, U3.42 (DAC_EXTI9/I2C3_SMBA/TIM1_CH2/USART1_TX/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)
/UAER2_RX: P7.2, U3.52 (PC11/ADC1_EXTI11/ADC2_EXTI11/ADC3_EXTI1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)
/UAER2_TX: P7.3, U3.51 (PC10/I2S3_CK/SDIO_D2/SPI3_SCK/UART4_TX/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)
/USBEN: R15.2, U3.62 (CAN1_TX/DAC_EXTI9/I2C1_SDA/I2S2_WS/SDIO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)
/VBUS: C28.2, C29.2, P5.1 (VCC), P6.1, R14.1, U4.3 (VI), U5.3 (VI)
/debug1: P8.3, U3.58 (CAN2_TX/I2C1_SCL/TIM4_CH1/USART1_TX/PB6)
/debug2: P8.4, U3.59 (I2C1_SDA/TIM4_CH2/USART1_RX/PB7)
/debug3: P8.5, U3.61 (CAN1_RX/I2C1_SCL/SDIO_D4/TIM10_CH1/TIM4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)
/debug4: P8.1, U3.50 (ADC1_EXTI15/ADC2_EXTI15/ADC3_EXTI15/I2S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)
/debug5: P8.2, U3.54 (PD2/SDIO_CMD/TIM3_ETR/UART5_RX)
GND: C1.1, C2.1, C3.1, C4.1, C6.2, C7.2, C8.2, C9.2, C10.2, C11.2, C12.2, C13.2, C14.2, C15.2, C16.2, C17.2, C18.2, C19.2, C20.2, C21.2, C22.2, C23.2, C24.2, C25.1, C26.2, C27.1, C28.1, C29.1, C30.2, D1.1 (K), D2.1 (K), D3.1 (K), D4.1 (K), D5.1 (K), L1.1, P1.2 (GND), P1.3 (GND), P1.4 (GND), P1.5 (GND), P2.5, P2.6, P3.1, P4.4, P5.4 (GND), P5.5 (shield), P6.2, P7.1, R8.2, R9.2, R11.2, SW2.1, U1.8 (GND), U1.9 (GND), U1.12 (GND), U1.14 (GND), U1.17 (GND), U2.5 (GND), U2.9 (GND), U2.18 (DGND_GUARD), U2.22 (DGND), U2.23 (DSUB_PADS), U2.24 (DSUB_CORE), U2.49 (AGND), U3.12 (VSSA), U3.18 (VSS), U3.63 (VSS), U4.1 (GND/ADJ), U5.1 (GND/ADJ)
unnamed: C1.2, L1.2, L2.1, P1.1 (RF)
unnamed: C3.2, C5.2, L2.2
unnamed: C5.1, U1.11 (ANT)
unnamed: C8.1, U3.5 (PH0/RCC_OSC_IN), Y1.2
unnamed: C9.1, U3.6 (PH1/RCC_OSC_OUT), Y1.1
unnamed: C10.1, U3.3 (PC14/RCC_OSC32_IN), Y2.2
unnamed: C11.1, U3.4 (PC15/ADC1_EXTI15/ADC2_EXTI15/ADC3_EXTI1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), Y2.1
unnamed: C13.1, U3.31 (VCAP_1)
unnamed: C14.1, U3.47 (VCAP_2)
unnamed: C21.1, U2.43 (XOSC16_Q1), Y3.1
unnamed: C22.1, U2.42 (XOSC16_Q2), Y3.2
unnamed: D1.2 (A), R1.2
unnamed: D2.2 (A), R3.2
unnamed: D3.2 (A), R4.2
unnamed: D4.2 (A), R5.2
unnamed: D5.2 (A), R14.2
unnamed: L3.1, U1.4 (RF_P), U2.6 (RF_P)
unnamed: L3.2, U1.2 (RF_N), U2.8 (RF_N)
unnamed: P2.3, R2.1
unnamed: P2.4, R6.2
unnamed: P4.2, U3.46 (SYS_JTMS-SWDIO/PA13)
unnamed: P4.3, U3.49 (SYS_JTCK-SWCLK/PA14)
unnamed: P5.2 (D-), R17.2
unnamed: P5.3 (D+), R18.2, R19.1
unnamed: Q1.1 (B), R15.1, R16.1
unnamed: Q1.3 (C), R19.2
unnamed: R8.1, U1.15 (BIAS)
unnamed: R10.1, U3.1 (VBAT)
unnamed: R11.1, U2.45 (R_BIAS)
unnamed: R12.1, R13.2, U2.25 (DVDD3.3)
unnamed: R17.1, U3.44 (ADC1_EXTI11/ADC2_EXTI11/ADC3_EXTI11/CAN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)
unnamed: R18.1, U3.45 (CAN1_TX/TIM1_ETR/USART1_RTS/USB_OTG_FS_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)
unnamed: U1.3 (TXRX), U2.7 (TXRX_SWITCH)

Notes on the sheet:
tx line inductor
Embedded bootloader • USART1 (PA9/PA10) • USART3 (PB10/11 and PC10/11)
!!!

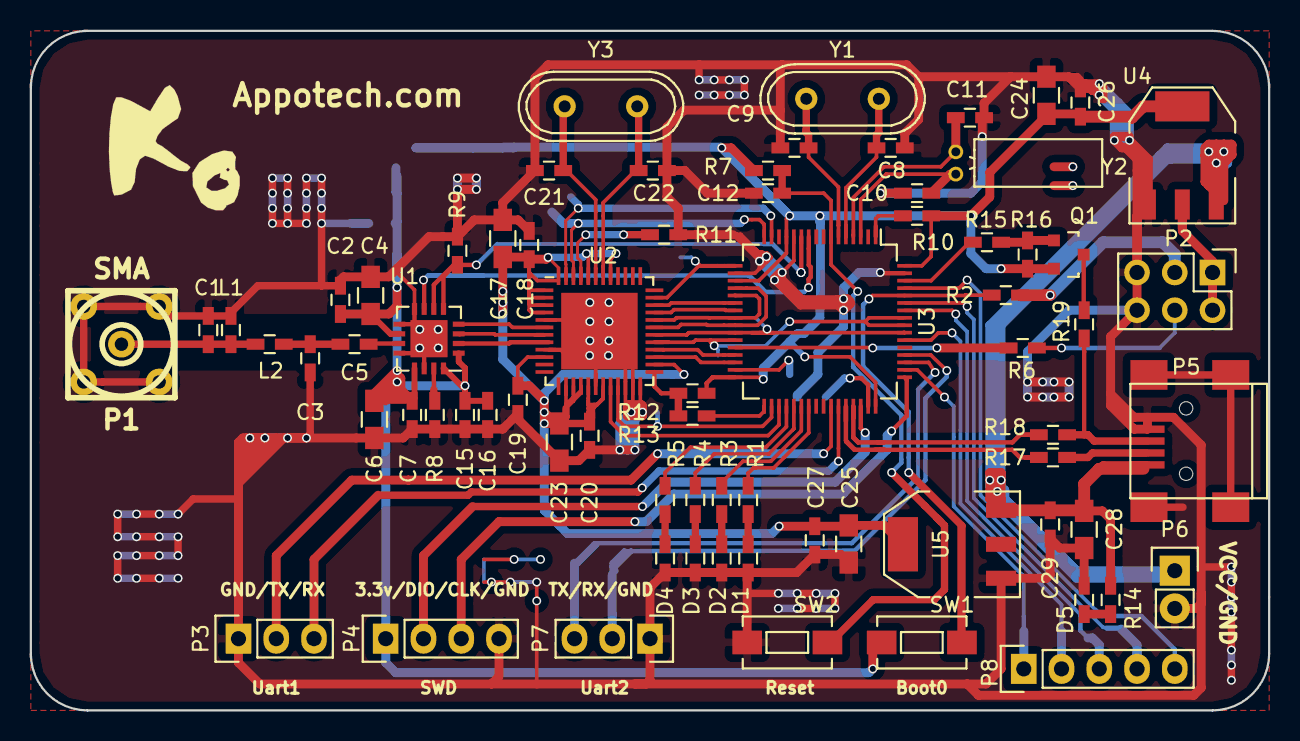
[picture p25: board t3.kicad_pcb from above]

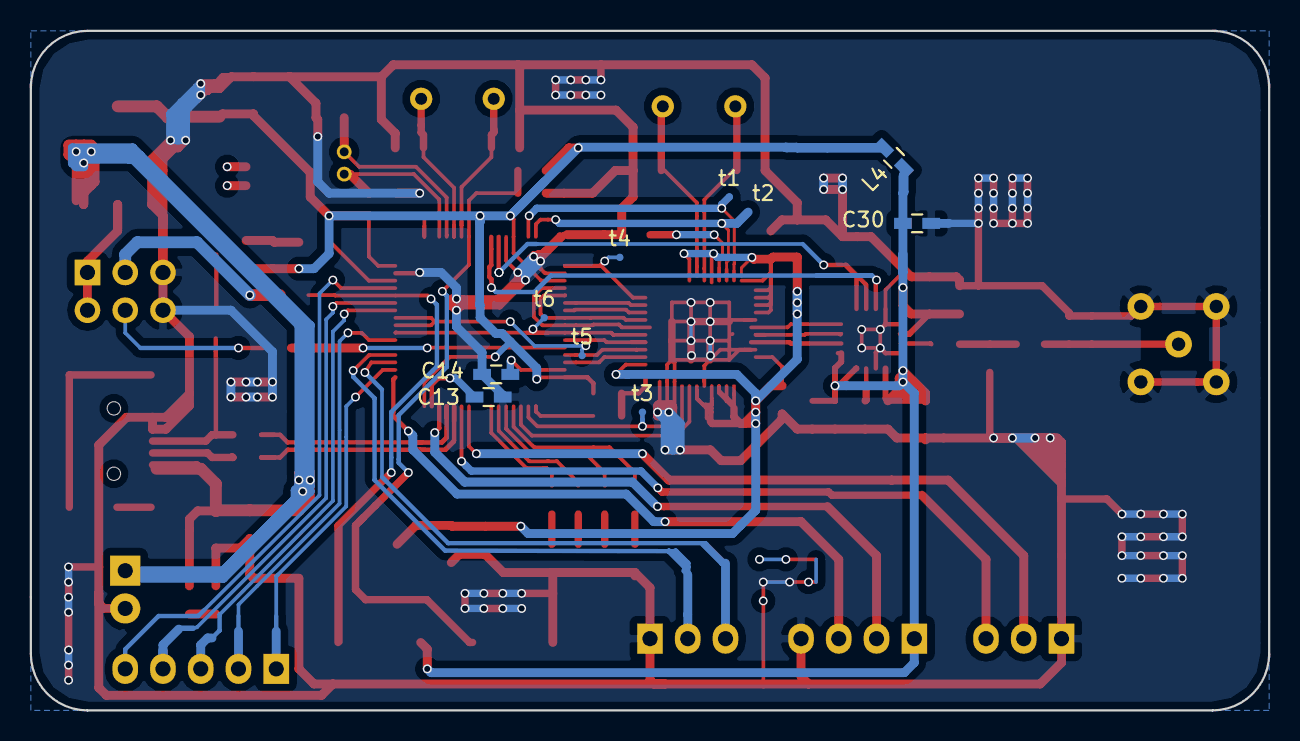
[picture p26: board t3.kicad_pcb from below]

Board: 2 copper layers, 83.3 x 45.7 mm, 82 parts (10 on the bottom side), 71 nets.

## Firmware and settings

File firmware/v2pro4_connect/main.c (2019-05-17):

/*
 * This file is part of the ubermini project.
 *
 * Copyright (C) 2017 Kage Shen <kgat96@gmail.com>
 *
 * This program is free software; you can redistribute it and/or modify
 * it under the terms of the GNU General Public License version 2 as
 * published by the Free Software Foundation.
 */

#include <libopencm3/stm32/rcc.h>
#include <libopencm3/stm32/gpio.h>
#include <libopencm3/stm32/usart.h>

#include <libopencm3/cm3/nvic.h>
#include <libopencm3/stm32/exti.h>
#include <libopencm3/stm32/timer.h>
#include <libopencm3/stm32/spi.h>

#include <libopencm3/stm32/dma.h>
#include <libopencm3/stm32/wwdg.h>

//#include <errno.h>
//#include <stdio.h>
//#include <unistd.h>

#include <string.h>

#include "config.h"
#include "cc.h"
#include "usbhid.h"
#include "uart.h"
#include "ble.h"

void delay_us(u32 us);
void delay_ms(u32 us);

__attribute__((optimize("-O0"))) void delay_us(u32 us)
{
    while(us--) {
        u32 i = 17;
        while (i--)
            __asm__("nop");
    }
}

__attribute__((optimize("-O0"))) void delay_ms(u32 ms)
{
    while(ms--)
        delay_us(1000);
}

__attribute__((optimize("-O0"))) void delay(void)
{
    u32 i;
    for (i = 0; i < 1000; i++) { /* Wait a bit. */
        __asm__("nop");
    }
}

static void usart_setup(void)
{
    /* Enable clocks for USART1. */
    rcc_periph_clock_enable(RCC_USART1);

    /* Setup USART1 parameters. */
    usart_set_baudrate(nUSART, 115200);
    usart_set_databits(nUSART, 8);
    usart_set_stopbits(nUSART, USART_STOPBITS_1);
    usart_set_mode(nUSART, USART_MODE_TX);
    usart_set_parity(nUSART, USART_PARITY_NONE);
    usart_set_flow_control(nUSART, USART_FLOWCONTROL_NONE);

    /* Finally enable the USART. */
    usart_enable(nUSART);
}

static void gpio_setup(void)
{
    /* Enable GPIO clock. */
    rcc_periph_clock_enable(RCC_GPIOA);
    rcc_periph_clock_enable(RCC_GPIOB);
    rcc_periph_clock_enable(RCC_GPIOC);
    rcc_periph_clock_enable(RCC_GPIOD);

    /* Set GPIO LED. */
    gpio_mode_setup(GPIOC, GPIO_MODE_OUTPUT, GPIO_PUPD_PULLDOWN, PIN_LED1); // LED1
    gpio_mode_setup(GPIOC, GPIO_MODE_OUTPUT, GPIO_PUPD_PULLDOWN, PIN_LED2); // LED2
    gpio_mode_setup(GPIOC, GPIO_MODE_OUTPUT, GPIO_PUPD_PULLDOWN, PIN_LED3); // LED3
    gpio_mode_setup(GPIOC, GPIO_MODE_OUTPUT, GPIO_PUPD_PULLDOWN, PIN_LED4); // LED4

    /* Setup GPIO pins for USART1 transmit. */
    gpio_mode_setup(GPIOA, GPIO_MODE_AF, GPIO_PUPD_PULLDOWN, GPIO9);
    //gpio_mode_setup(GPIOA, GPIO_MODE_AF, GPIO_PUPD_PULLDOWN, GPIO10);

    /* Setup USART1 TX/RX pin as alternate function. */
    gpio_set_af(GPIOA, GPIO_AF7, GPIO9);   // tx
    //gpio_set_af(GPIOA, GPIO_AF7, GPIO10);  // rx

    gpio_mode_setup(GPIOA, GPIO_MODE_OUTPUT, GPIO_PUPD_PULLUP, GPIO10);

    /* GPIO spi pins */
    gpio_mode_setup(GPIOC, GPIO_MODE_OUTPUT, GPIO_PUPD_PULLUP, PIN_MOSI | PIN_SCLK);
    gpio_mode_setup(GPIOC, GPIO_MODE_INPUT,  GPIO_PUPD_PULLUP, PIN_MISO);
    gpio_mode_setup(GPIOD, GPIO_MODE_OUTPUT, GPIO_PUPD_PULLUP, PIN_CSN);

    /* other pins */
    gpio_mode_setup(GPIOB, GPIO_MODE_OUTPUT, GPIO_PUPD_PULLUP, PIN_RX | PIN_TX | PIN_BTGR);
    gpio_mode_setup(GPIOC, GPIO_MODE_OUTPUT, GPIO_PUPD_PULLUP, PIN_PAEN | PIN_HGM);

    gpio_mode_setup(GPIOB, GPIO_MODE_OUTPUT,  GPIO_PUPD_PULLUP, 1 << 13); // ?????

    gpio_mode_setup(GPIOA, GPIO_MODE_INPUT, GPIO_PUPD_PULLUP, PIN_GIO6);

    BTGR_CLR(); TX_CLR(); RX_CLR();

    LED1_SET();LED2_SET();LED3_SET();LED4_SET();

    /* USB pins */
    gpio_mode_setup(GPIOA, GPIO_MODE_AF, GPIO_PUPD_NONE, GPIO11 | GPIO12 );
    gpio_set_af(GPIOA, GPIO_AF10, GPIO11 | GPIO12 );

}

static void spi_setup(void)
{
    /*
     *       NSS          SCK                   MISO            MOSI
     *   --------------   -------------------   -------------   ---------------
     * SPI3  PA15*, PA4*  PB3*, PC10*           PB4*, PC11*     PB5*, PD6, PC12*
     */

     // set spi sck PB3
     gpio_mode_setup(GPIOB, GPIO_MODE_AF, GPIO_PUPD_PULLUP, GPIO3);
     gpio_set_af(GPIOB, GPIO_AF6, GPIO3);

     // set spi MISO PB4
     gpio_mode_setup(GPIOB, GPIO_MODE_AF, GPIO_PUPD_PULLUP, GPIO4);
     gpio_set_af(GPIOB, GPIO_AF6, GPIO4);
 
     // set spi MoSI PB5
     //gpio_mode_setup(GPIOB, GPIO_MODE_AF, GPIO_PUPD_PULLUP, GPIO5);
     //gpio_set_af(GPIOB, GPIO_AF6, GPIO5);

     rcc_periph_clock_enable(RCC_SPI3);

     // slave mode, 8 bit, one line only,
     //SPI3_CR1 = SPI_CR1_SSI | SPI_CR1_BIDIMODE_1LINE_BIDIR | SPI_CR1_SSM | SPI_CR1_CPHA | SPI_CR1_CPOL;
     SPI3_CR1 = SPI_CR1_SSI | SPI_CR1_BIDIMODE_1LINE_BIDIR | SPI_CR1_SSM;

     SPI3_CR2 = SPI_CR2_RXNEIE; // Rx buffer not empty interrupt enable
     nvic_enable_irq(NVIC_SPI3_IRQ);

     //SPI3_CR2 |= 1;           // RX dma mode
}

static void tim_setup(void)
{
#if 0
    /* master/slave mode */
    rcc_periph_clock_enable(RCC_TIM3);  /* Enable TIM3 clock. */
    nvic_enable_irq(NVIC_TIM3_IRQ);     /* Enable TIM3 interrupt. */
    timer_reset(TIM3);                  /* Reset TIM3 peripheral. */
    timer_set_mode(TIM3, TIM_CR1_CKD_CK_INT, TIM_CR1_CMS_EDGE, TIM_CR1_DIR_UP);

    timer_set_prescaler(TIM3, 5);       // rcc_apb1_frequency(42MHz) * 2 / (5 + 1) = 14MHz
    timer_disable_preload(TIM3);        /* Enable preload. */
    timer_continuous_mode(TIM3);        /* Continous mode. */
    timer_set_period(TIM3, 4374);       // 312.5us / (1/14MHz) = 14 * 312.5

    /* Counter enable. */
    timer_enable_counter(TIM3);
    /* Enable commutation interrupt. */
    timer_enable_irq(TIM3, TIM_DIER_UIE);
#endif

    ////////////////////////////////////////////////

    rcc_periph_clock_enable(RCC_TIM2);  /* Enable TIM2 clock. */
    nvic_enable_irq(NVIC_TIM2_IRQ);     /* Enable TIM2 interrupt. */
    timer_reset(TIM2);                  /* Reset TIM2 peripheral. */

    timer_set_mode(TIM2, TIM_CR1_CKD_CK_INT, TIM_CR1_CMS_EDGE, TIM_CR1_DIR_UP);

    timer_set_prescaler(TIM2, 84-1);    // rcc_apb1_frequency(42MHz) * 2 / (84) = 1MHz
    timer_disable_preload(TIM2);        /* Enable preload. */
    timer_continuous_mode(TIM2);        /* Continous mode. */

    /* Period. */
    timer_set_period(TIM2, 0xffffffff);
    TIM2_CNT = 0xffffffff - 10;         // the first time interrupt have bug ???

    /* Disable outputs. */
    timer_disable_oc_output(TIM2, TIM_OC1);
    timer_disable_oc_output(TIM2, TIM_OC2);
    timer_disable_oc_output(TIM2, TIM_OC3);
    timer_disable_oc_output(TIM2, TIM_OC4);

    /* -- OC1 configuration -- */
#if 0
    /* Configure global mode of line 1. */
    timer_disable_oc_clear(TIM2, TIM_OC1);
    timer_disable_oc_preload(TIM2, TIM_OC1);
    timer_set_oc_slow_mode(TIM2, TIM_OC1);
    timer_set_oc_mode(TIM2, TIM_OC1, TIM_OCM_FROZEN);

    /* Set the capture compare value for OC1. */
    timer_set_oc_value(TIM2, TIM_OC1, 1000);

    /* Enable commutation interrupt. */
    timer_enable_irq(TIM2, TIM_DIER_CC1IE);
#endif
    /* ---- */
    /* Enable commutation interrupt. */
    //timer_enable_irq(TIM2, TIM_DIER_UIE);

    /* Counter enable. */
    timer_enable_counter(TIM2);
}

int main(void)
{
    WWDG_CR = 0;

    gpio_setup();

    usart_setup();

    kputs("\nubermini RUN\n");

    printf("system uart output\n");

    cc_reset();

    cc_init();

    delay(); // why ???

    /* Enable external high-speed oscillator 16MHz. */
    rcc_osc_bypass_enable(RCC_HSE);
    rcc_clock_setup_hse_3v3(&rcc_hse_16mhz_3v3[RCC_CLOCK_3V3_168MHZ]);
    rcc_periph_clock_enable(RCC_OTGFS);

    /* Setup USART1 parameters. */
    usart_set_baudrate(USART1, 2000000);

    LED1_CLR();LED2_CLR();LED3_CLR();LED4_CLR();

    kputs("system clock init done!\n");

    tim_setup();
    spi_setup();

    spi_enable(SPI3);
    cc_clean_fifo();

    ble_init();

    while (1) {
        ble_process();
    }

    return 0;
}

/*
 * Check at compile time that something is of a particular type.
 * Always evaluates to 1 so you may use it easily in comparisons.
 */
#define typeof __typeof__
#define typecheck(type,x) \
({  type __dummy; \
    typeof(x) __dummy2; \
    (void)(&__dummy == &__dummy2); \
    1; \
})

#define time_after(a,b)     \
        (typecheck(u32, a) && \
         typecheck(u32, b) && \
         ((int)((b) - (a)) < 0))
#define time_before(a,b)    time_after(b,a)

u32 tim2_jiffies(u32 n);
int tim2_before(u32 t);
int tim2_after(u32 t);

u32 tim2_jiffies(u32 n)
{
    u32 t = TIM2_CNT;
    return t + n;
}

int tim2_before(u32 t)
{
    return time_before((u32)TIM2_CNT, t);
}

int tim2_after(u32 t)
{
    return time_after((u32)TIM2_CNT, t);
}

/* 1us */
void tim2_isr(void)
{
    //kputc('#');
    if (TIM_SR(TIM2) & TIM_SR_UIF) {
        TIM_SR(TIM2) = ~TIM_SR_UIF;
        UART_TOG();
    }
}

/* 312.5us */
void tim3_isr(void)
{
    //kputc('-');
    if (TIM_SR(TIM3) & TIM_SR_UIF) {
        TIM_SR(TIM3) = ~TIM_SR_UIF;
        clk3125n ++;
    }
}

void spi3_isr(void)
{
    //kputc('*');
    while (SPI3_SR & SPI_SR_RXNE) {
        ble_rxpacket[ble_packet_len] = SPI3_DR;
        if (ble_packet_len < (sizeof(ble_rxpacket)-1))
            ble_packet_len++;
    }
}

#if 0

/* DMA buffers */
#define DMA_SIZE        50
u8 rxbuf1[DMA_SIZE];
u8 rxbuf2[DMA_SIZE];

#define UES_DMA_STREAM  DMA_STREAM0
#define UES_DMA_CONUR   DMA1

static void dma_setup(void)
{
    /* DAC channel 1 uses DMA controller 1 Stream 5 Channel 7. */
    /* Enable DMA1 clock and IRQ */
    rcc_periph_clock_enable(RCC_DMA1);
    nvic_enable_irq(NVIC_DMA1_STREAM0_IRQ);

    dma_stream_reset(UES_DMA_CONUR, UES_DMA_STREAM);
    dma_set_priority(UES_DMA_CONUR, UES_DMA_STREAM, DMA_SxCR_PL_LOW);
    dma_set_memory_size(UES_DMA_CONUR, UES_DMA_STREAM, DMA_SxCR_MSIZE_8BIT);
    dma_set_peripheral_size(UES_DMA_CONUR, UES_DMA_STREAM, DMA_SxCR_PSIZE_8BIT);
    dma_enable_memory_increment_mode(UES_DMA_CONUR, UES_DMA_STREAM);
    dma_enable_circular_mode(UES_DMA_CONUR, UES_DMA_STREAM);
    dma_set_transfer_mode(UES_DMA_CONUR, UES_DMA_STREAM, DMA_SxCR_DIR_PERIPHERAL_TO_MEM);

    /* The register to target is the DAC1 8-bit right justified data register */
    dma_set_peripheral_address(UES_DMA_CONUR, UES_DMA_STREAM, (uint32_t) &SPI3_DR);
    /* The array v[] is filled with the waveform data to be output */
    dma_set_memory_address(UES_DMA_CONUR, UES_DMA_STREAM, (uint32_t) rxbuf1);
    dma_set_memory_address_1(UES_DMA_CONUR, UES_DMA_STREAM, (uint32_t) rxbuf2);
    dma_set_number_of_data(UES_DMA_CONUR, UES_DMA_STREAM, DMA_SIZE);

    dma_channel_select(UES_DMA_CONUR, UES_DMA_STREAM, DMA_SxCR_CHSEL_0);
    dma_enable_double_buffer_mode(UES_DMA_CONUR, UES_DMA_STREAM);

    dma_enable_transfer_complete_interrupt(UES_DMA_CONUR, UES_DMA_STREAM);
    dma_enable_transfer_error_interrupt(UES_DMA_CONUR, UES_DMA_STREAM);

    dma_enable_stream(UES_DMA_CONUR, UES_DMA_STREAM);
}

/*
 * The active buffer is the one with an active DMA transfer.
 * The idle buffer is the one we can read/write between transfers.
 */
u8 *active_rxbuf = &rxbuf1[0];
u8 *idle_rxbuf = &rxbuf2[0];

/*--------------------------------------------------------------------*/
/* The ISR simply provides a test output for a CRO trigger */
void dma1_stream0_isr(void)
{
    if (dma_get_interrupt_flag(UES_DMA_CONUR, UES_DMA_STREAM, DMA_TCIF)) {
        dma_clear_interrupt_flags(UES_DMA_CONUR, UES_DMA_STREAM, DMA_TCIF);
        if (DMA_SCR(UES_DMA_CONUR, UES_DMA_STREAM) & DMA_SxCR_CT) {
            active_rxbuf = &rxbuf2[0];
            idle_rxbuf = &rxbuf1[0];
        } else {
            active_rxbuf = &rxbuf1[0];
            idle_rxbuf = &rxbuf2[0];
        }
        // TODO
    } else if (dma_get_interrupt_flag(UES_DMA_CONUR, UES_DMA_STREAM, DMA_TEIF)) {
        dma_clear_interrupt_flags(UES_DMA_CONUR, UES_DMA_STREAM, DMA_TEIF);
    }
}

#endif

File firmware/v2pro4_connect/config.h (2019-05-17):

/*
 * This file is part of the ubermini project.
 *
 * Copyright (C) 2016 Kage Shen <kgat96@gmail.com>
 *
 * This program is free software; you can redistribute it and/or modify
 * it under the terms of the GNU General Public License version 2 as
 * published by the Free Software Foundation.
 */

#ifndef __CONFIG_H
#define __CONFIG_H

#include <stdio.h>

#include <libopencm3/stm32/rcc.h>
#include <libopencm3/stm32/gpio.h>
#include <libopencm3/stm32/usart.h>

#include <libopencm3/cm3/nvic.h>
#include <libopencm3/stm32/exti.h>
#include <libopencm3/stm32/timer.h>
#include <libopencm3/stm32/spi.h>

#include <libopencm3/stm32/dma.h>

typedef unsigned int u32;
typedef unsigned short u16;
typedef unsigned char u8;
typedef unsigned long int u64;

typedef volatile unsigned int vu32;
typedef volatile unsigned short vu16;
typedef volatile unsigned char vu8;
typedef volatile unsigned long int vu64;

#define NULL ((void *)0)

#define UNUSED(x)   (void)(x)

#define BIT(n)      (0x1U << (n))

#define PIN_MOSI    GPIO11      /* Pc.11  */
#define PIN_MISO    GPIO10      /* Pc.10  */
#define PIN_SCLK    GPIO12      /* Pc.12  */
#define PIN_CSN     GPIO2       /* Pd.2  */

#define PIN_GIO6    GPIO15      /* Pa.15  */

#define PIN_RX      GPIO7      /* Pb.7 */
#define PIN_TX      GPIO6      /* Pb.6 */
#define PIN_BTGR    GPIO8      /* Pb.8 */

#define PIN_LED1   GPIO3       /* Pc.3 LED1 */
#define PIN_LED2   GPIO2       /* Pc.2 LED2 */
#define PIN_LED3   GPIO1       /* Pc.1 LED3 */
#define PIN_LED4   GPIO0       /* Pc.0 LED4 */

#define PIN_PAEN    GPIO13       /* Pc.13  */
#define PIN_HGM     GPIO14       /* Pc.14  */

#define UART_RX         GPIO10       /* Pa.10  */

#define UART_SET()      gpio_set(GPIOA, UART_RX)
#define UART_CLR()      gpio_clear(GPIOA, UART_RX)
#define UART_TOG()      gpio_toggle(GPIOA, UART_RX)

#define LED1_SET()      gpio_set(GPIOC, PIN_LED1)
#define LED1_CLR()      gpio_clear(GPIOC, PIN_LED1)
#define LED1_TOG()      gpio_toggle(GPIOC, PIN_LED1)

#define LED2_SET()      gpio_set(GPIOC, PIN_LED2)
#define LED2_CLR()      gpio_clear(GPIOC, PIN_LED2)
#define LED2_TOG()      gpio_toggle(GPIOC, PIN_LED2)

#define LED3_SET()      gpio_set(GPIOC, PIN_LED3)
#define LED3_CLR()      gpio_clear(GPIOC, PIN_LED3)
#define LED3_TOG()      gpio_toggle(GPIOC, PIN_LED3)

#define LED4_SET()      gpio_set(GPIOC, PIN_LED4)
#define LED4_CLR()      gpio_clear(GPIOC, PIN_LED4)
#define LED4_TOG()      gpio_toggle(GPIOC, PIN_LED4)

#define RX_SET()        gpio_set(GPIOB, PIN_RX)
#define RX_CLR()        gpio_clear(GPIOB, PIN_RX)
#define TX_SET()        gpio_set(GPIOB, PIN_TX)
#define TX_CLR()        gpio_clear(GPIOB, PIN_TX)

#define CSN_SET()    gpio_set(GPIOD, PIN_CSN)
#define CSN_CLR()    gpio_clear(GPIOD, PIN_CSN)
#define SCLK_SET()   gpio_set(GPIOC, PIN_SCLK)
#define SCLK_CLR()   gpio_clear(GPIOC, PIN_SCLK)
#define MOSI_SET()   gpio_set(GPIOC, PIN_MOSI)
#define MOSI_CLR()   gpio_clear(GPIOC, PIN_MOSI)

#define GIO6_SET()   gpio_set(GPIOA, PIN_GIO6)
#define GIO6_CLR()   gpio_clear(GPIOA, PIN_GIO6)
#define BTGR_SET()   gpio_set(GPIOB, PIN_BTGR)
#define BTGR_CLR()   gpio_clear(GPIOB, PIN_BTGR)
#define MISO()       gpio_get(GPIOC, PIN_MISO)

#define PAEN()      gpio_get(GPIOC, PIN_PAEN)
#define PAEN_SET()  gpio_set(GPIOC, PIN_PAEN)
#define PAEN_CLR()  gpio_clear(GPIOC, PIN_PAEN)
#define HGM()       gpio_get(GPIOC, PIN_HGM)
#define HGM_SET()   gpio_set(GPIOC, PIN_HGM)
#define HGM_CLR()   gpio_clear(GPIOC, PIN_HGM)

#define U1_VENDORID    0x1d50
#define U1_PRODUCTID   0x6002

#define UBERTOOTH_API_VERSION 0x0102

#define BULK_IN_EP      0x82
#define BULK_OUT_EP     0x05
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

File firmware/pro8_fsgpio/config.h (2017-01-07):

/*
 * This file is part of the ubertoothp project.
 *
 * Copyright (C) 2016 Kage Shen <kgat96@gmail.com>
 *
 * This program is free software; you can redistribute it and/or modify
 * it under the terms of the GNU General Public License version 2 as
 * published by the Free Software Foundation.
 */

#ifndef __CONFIG_H
#define __CONFIG_H

typedef unsigned int u32;
typedef unsigned short u16;
typedef unsigned char u8;

typedef volatile unsigned int vu32;
typedef volatile unsigned short vu16;
typedef volatile unsigned char vu8;

#define NULL ((void *)0)


#define PIN_MOSI    GPIO7       /* Pa.7  */
#define PIN_MISO    GPIO6       /* Pa.6  */
#define PIN_GIO6    GPIO3       /* Pa.3  */

#define PIN_ATEST1  GPIO1       /* Pa.1  */
#define PIN_ATEST2  GPIO2       /* Pa.2  */

#define PIN_CC3V3   GPIO12      /* Pb.12 */
#define PIN_RX      GPIO11      /* Pb.11 */
#define PIN_TX      GPIO10      /* Pb.10 */
#define PIN_BTGR    GPIO14      /* Pb.14 */
#define PIN_GIO1    GPIO13      /* Pb.13 */

#define PIN_RXLED   GPIO8       /* Pc.8 LED1 */
#define PIN_TXLED   GPIO7       /* Pc.7 LED2 */
#define PIN_USRLED  GPIO6       /* Pc.6 LED3 */

#define PIN_CSN     GPIO5       /* Pc.5  */
#define PIN_SCLK    GPIO4       /* Pc.4  */
#define PIN_PAEN    GPIO3       /* Pc.3  */
#define PIN_HGM     GPIO2       /* Pc.2  */

//#define USRLED        (FIO1PIN & PIN_USRLED)
#define USRLED_SET()    gpio_set(GPIOC, PIN_USRLED)
#define USRLED_CLR()    gpio_clear(GPIOC, PIN_USRLED)
//#define RXLED         (FIO1PIN & PIN_RXLED)
#define RXLED_SET()     gpio_set(GPIOC, PIN_RXLED)
#define RXLED_CLR()     gpio_clear(GPIOC, PIN_RXLED)
//#define TXLED         (FIO1PIN & PIN_TXLED)
#define TXLED_SET()     gpio_set(GPIOC, PIN_TXLED)
#define TXLED_CLR()     gpio_clear(GPIOC, PIN_TXLED)

#define CC3V3_SET()     gpio_set(GPIOB, PIN_CC3V3)
#define CC3V3_CLR()     gpio_clear(GPIOB, PIN_CC3V3)
#define RX_SET()        gpio_set(GPIOB, PIN_RX)
#define RX_CLR()          gpio_clear(GPIOB, PIN_RX)
#define TX_SET()          gpio_set(GPIOB, PIN_TX)
#define TX_CLR()          gpio_clear(GPIOB, PIN_TX)
#define CSN_SET()    gpio_set(GPIOC, PIN_CSN)
#define CSN_CLR()    gpio_clear(GPIOC, PIN_CSN)
#define SCLK_SET()   gpio_set(GPIOC, PIN_SCLK)
#define SCLK_CLR()   gpio_clear(GPIOC, PIN_SCLK)
#define MOSI_SET()   gpio_set(GPIOA, PIN_MOSI)
#define MOSI_CLR()   gpio_clear(GPIOA, PIN_MOSI)
//#define GIO6       (FIO2PIN & PIN_GIO6)
#define GIO6_SET()   gpio_set(GPIOA, PIN_GIO6)
#define GIO6_CLR()   gpio_clear(GPIOA, PIN_GIO6)
#define BTGR_SET()   gpio_set(GPIOB, PIN_BTGR)
#define BTGR_CLR()   gpio_clear(GPIOB, PIN_BTGR)
#define MISO()       gpio_get(GPIOA, PIN_MISO)

#define PAEN()      gpio_get(GPIOC, PIN_PAEN)
#define PAEN_SET()  gpio_set(GPIOC, PIN_PAEN)
#define PAEN_CLR()  gpio_clear(GPIOC, PIN_PAEN)
#define HGM()       gpio_get(GPIOC, PIN_HGM)
#define HGM_SET()   gpio_set(GPIOC, PIN_HGM)
#define HGM_CLR()   gpio_clear(GPIOC, PIN_HGM)

#include <libopencm3/stm32/usart.h>

#define nUSART USART1

#define kputc(a) usart_send_blocking(nUSART, a)
void kputhex(unsigned int value, int digits);
void kputs(char *s);
void delay(void);

#endif

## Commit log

2016-11-08 init repo
    [CC2430-CC2591EM_2_0_PARTLIST.xls, CC2520-CC2591EM_PARTLIST_zip.xls, artichoke.brd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]
2016-11-09 fix[1/x] ubertooth debug board
    [CC2430-CC2591EM_2_0_PARTLIST.xls, CC2520-CC2591EM_PARTLIST_zip.xls, stm32f4xx_af.csv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]
2016-11-11 fix[2/x] ubertooth debug board
    [preprocessor.xls, t3.sch]
2016-11-11 fix[3/x] ubertooth debug board
    [t3.sch]
2016-11-14 fix[4/x] ubertooth debug board
    [t3.sch]
2016-11-14 fix[5/x] ubertooth debug board
    [t3.kicad_pcb, t3.sch]
2016-11-15 fix[6/x] ubertooth debug board
    [t3.kicad_pcb, t3.sch]
2016-11-17 update[7/x] ubertooth debug board
    [t3.kicad_pcb, t3.sch]
2016-11-21 update[8/x] add logo & fix layout
    [t3.bom.csv, t3.csv, t3.kicad_pcb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]
2016-11-22 firmware: update libopencm3 lib @ win7
    [t3.kicad_pcb]
2016-11-22 firmware: build blink
    [t3.kicad_pcb]
2016-11-25 hardware: update gerber file
    [noname.kicad_pcb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]
2016-11-25 push LPC datasheet
    [ubertooth-one.sch]
2016-11-25 sch: t4
    [t3.bom.csv, t3.csv, t3.kicad_pcb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]
2016-12-04 add libbtbb source
    [ellysis-keyboard.csv]
2016-12-17 pro5 test uart dma
2016-12-21 chmod 755/766
    [artichoke.brd, artichoke.sch, broccoli.brd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]
2017-01-04 spectrum debug led
2017-01-12 fix two board to debug
    [cc.c, cc.h, cctest.c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]
2017-03-29 fix print ...
2017-03-29 rename uber
    [artichoke.brd, artichoke.sch, broccoli.brd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]
2017-04-23 hw v2 update
    [t1.kicad_pcb, t1.sch, t2.kicad_pcb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]
2017-05-07 hw v2 add pcb
    [ubermini.kicad_pcb, ubermini.sch]
2017-05-08 hw patch
    [ubermini.kicad_pcb]
2017-05-10 hw update
    [ubermini.kicad_pcb, ubermini.sch]
2017-05-12 hw: add spi flash
    [ubermini.kicad_pcb]
2017-05-15 add logo
    [ubermini.kicad_pcb, ubermini.sch]
2017-05-16 fix hw
    [ubermini.kicad_pcb]
2017-05-18 create gerber file
    [ubermini-B.Cu.gbr, ubermini-B.Mask.gbr, ubermini-B.SilkS.gbr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]
2017-05-31 upload pcb n2
    [ubermini-B.Cu.gbr, ubermini-B.Mask.gbr, ubermini-B.SilkS.gbr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]
2018-06-23 sync ..
    [ubermini-B.Cu.gbr, ubermini-B.Mask.gbr, ubermini-B.SilkS.gbr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]
2019-03-17 fix cc2400 tx problem
    [ble.c, cc.c, main.c]
